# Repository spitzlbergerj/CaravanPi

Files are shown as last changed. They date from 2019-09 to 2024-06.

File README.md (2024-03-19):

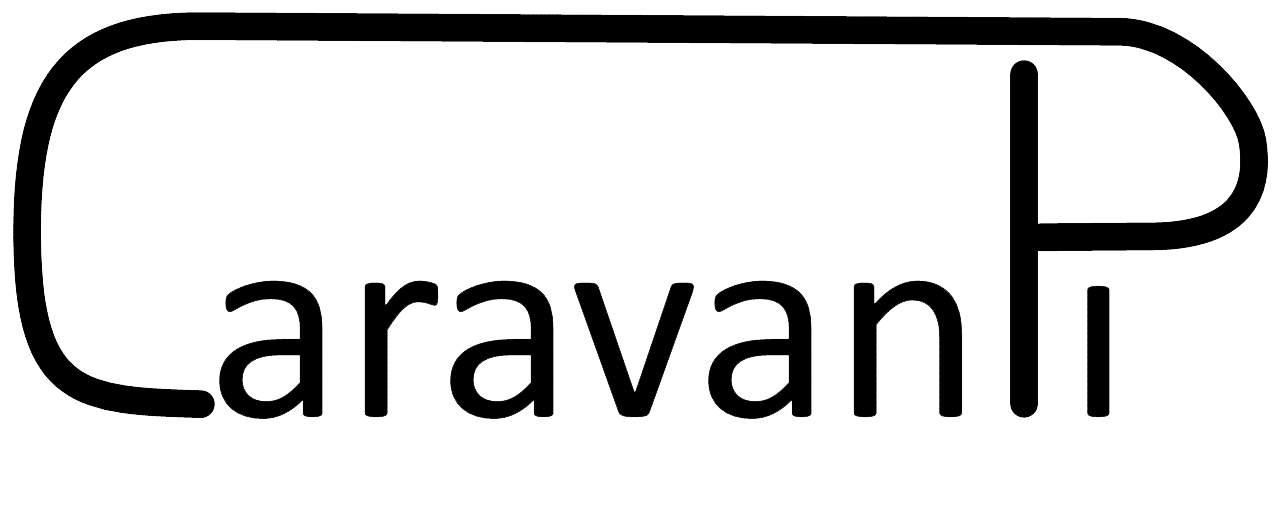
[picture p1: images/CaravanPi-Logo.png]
CaraavanPiLogo
  
# CaravanPi

ACHTUNG: Dokumentation nicht aktuell v2.0 noch nicht eingearbeitet

- [Website](https://www.CaravanPi.de)
- [Wiki](https://github.com/spitzlbergerj/CaravanPi/wiki/)
- [Platine bestellen](https://www.caravanpi.de/platine)

- [Newsletter abonnieren (Sendinblue/Brevo Plattform)](https://40fb016c.sibforms.com/serve/MUIFAH4-cq2k2-T8acJ-A43b4eFEC9NdXuY4Qsx0Z8AVap96J-xUTzrsRBFXvzXRIEBnFebbvgbXibn9NFGg8v5Qx55c4hzOQlpmxT23eU7bOGsW2ycUFhNx8PIrJcuGt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)

- [Movitation](#motivation)

## Aktualisierungen / Change Log

Details siehe / Please view [CHANGELOG.md](https://github.com/spitzlbergerj/CaravanPi/blob/master/CHANGELOG.md)

## Motivation

System zur Messung und Anzeige verschiedener Sensorenwerte in Wohnwagen, Caravans und Wohnmobilen, wie z.B. Klimawerte, Füllstände von Tanks und Gasflaschen sowie Nivellierungsdaten. Zur Darstellung wird die Software <a href="https://magicmirror.builders/">Magic Mirror</a> verwendet. 
Es existiert eine Schritt für Schritt Anleitung in deutsch. Englische Schnipsel sind bereits vorhanden und werden ausgebaut werden.
[direkt zur Anleitung](https://github.com/spitzlbergerj/CaravanPi/wiki/Home/)

Schemazeichnung | MagicMirror Anzeige (vor Grafana)
----- | -----
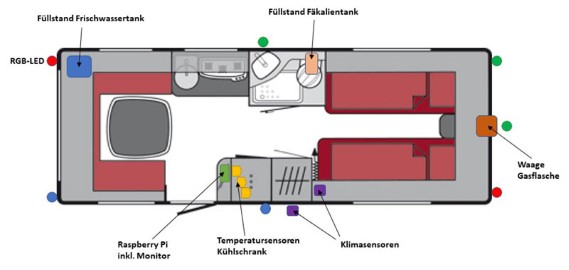
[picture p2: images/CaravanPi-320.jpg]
Schema
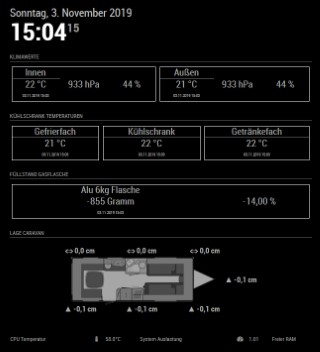
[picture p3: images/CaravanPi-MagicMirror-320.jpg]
MagicMirror
 | 
[größeres Bild](https://github.com/spitzlbergerj/CaravanPi/raw/master/images/CaravanPi.jpg) | [größeres Bild](https://github.com/spitzlbergerj/CaravanPi/raw/master/images/CaravanPi-MagicMirror.jpg) 

## Platinen Design

Die Platine liegt inzwischen in der version V6 vor in die wiederum eine Reihe von Verbesserungen eingeflossen sind.  
Vorderseite | Rückseite
----- | -----
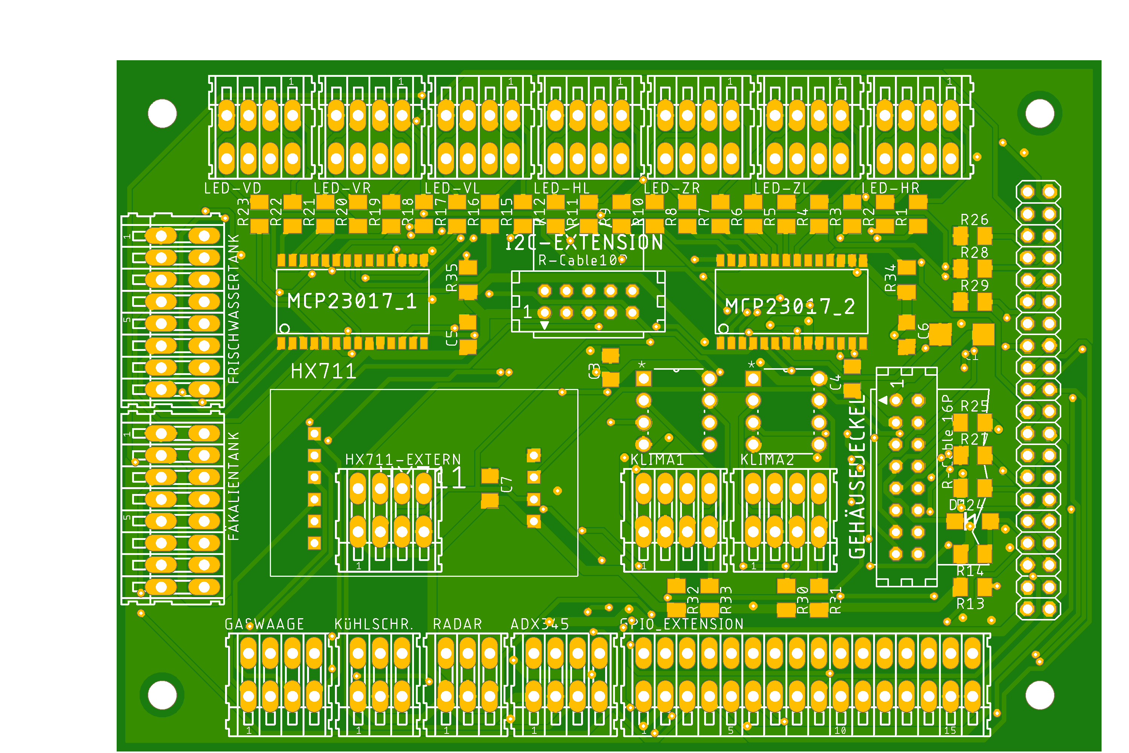
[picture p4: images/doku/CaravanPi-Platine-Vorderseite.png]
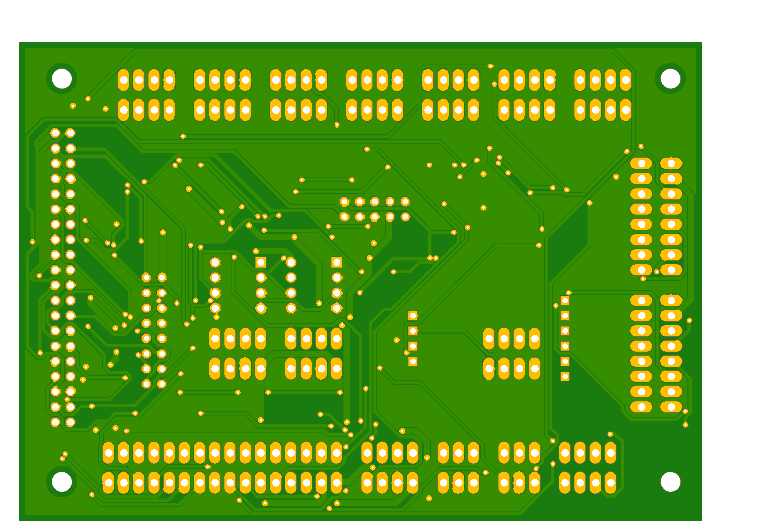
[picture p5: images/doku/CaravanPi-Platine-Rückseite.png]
 |  
Alle zum Bestellen der Platine benötigten Angaben und Dateien befinden sich im Verzeichnis circuit-board
Die Platine ist aus SMD Bauteilen aufgebaut. Als Klemmen verwendete ich früher WAGO Klemmen. Aufgrund des hohen Preises derselben bin ich inzwischen auf JST XA Stecker umgestiegen, die auch sehr viel flexibler beim Umbau sind. Bitte auf hochwertige Stecker achten, am besten original JST bauteile verwenden.
Ich kläre gerade mit JLCPCB, bei denen ich meine Platinen bestelle, ob diese Klemmen ebenfalls ab Werk aufgelötet werden können.

Ich habe beinahe immer einige Platinen vorrätig. Bitte nutzen Sie den Bestelllink oben, falls Sie Interesse an einer Platine haben.

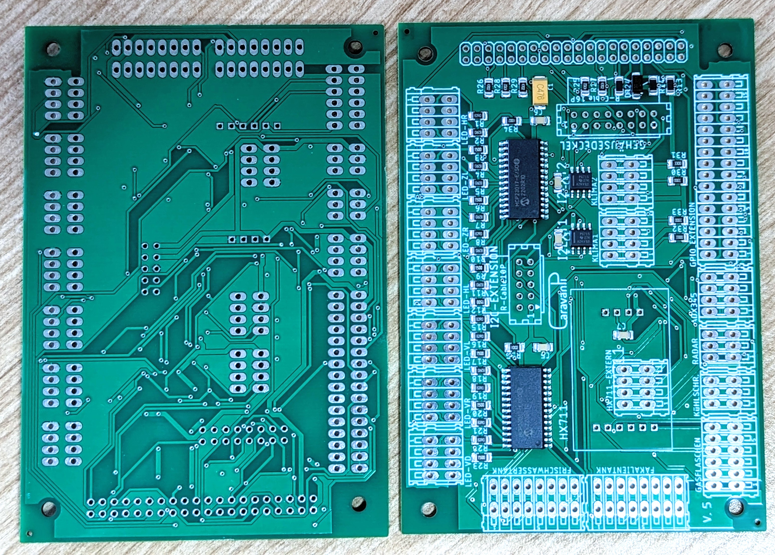
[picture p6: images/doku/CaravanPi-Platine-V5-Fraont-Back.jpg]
V5 back - front
 

## Dokumentation

Die Dokumentation findet im [Wiki](https://github.com/spitzlbergerj/CaravanPi/wiki/) statt. Dieses wird gerade neu aufgebaut, um auch alle neuen Funktionälitäten darstellen zu können.

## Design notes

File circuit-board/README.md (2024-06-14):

# Platinen Fertigung
In diesem Directory finden Sie alle Dateien, um eine Platine bei einem Dienstleister bestellen und fertigen lassen zu können.

# Versionen
Die CaravanPi Platine existiert inzwischen in mehreren Versionen

Version | Beschreibung
-----------|----
Version 1 | allererste Versuche, nicht für eine Auftragsproduktion geeignet
Version 2 | erste Version, die ich bei einem Dienstleister habe produzieren lassen <br/> enthält jedoch einen Fehler. Die Verdrahtung des VCC des Radar-Sensors war fälschlicherweise 3,3 V anstatt 5V
Version 3 | korrigierte Version, die ich erstmals bei JLCPCB inkl. SMD Bestückung habe fertigen lassen
Version 4 | Umstellung aller IC auf SMD
Version 5 | nur SMD Bauteile, Fehlerkorrektur R24 1-wire, Gaswaagen-Klemme 6 polig für A und B Kanal des HX711
Version 6 | Fehlerkorrektur HX711 mit 5V versorgt anstatt 3V3 um mehr Stabilität zu erzeugen

# Fertigung bei JLCPCB

Bei JLCPCB.com können Platinen sehr günstig, in hoher Qualität und inkl. SMD Bestückung online bestellt werden (siehe [Artikel in der Zeitschrift Make](https://www.heise.de/news/Ausprobiert-Platinen-mit-kostenloser-SMD-Bestueckung-5070776.html)). Den Bestellprozess habe ich [ausführlich beschrieben](jlcpcb.com/README.md). Alle benötigten Dateien sind in den jeweiligen Unterverzeichnissen der Versionen enthalten.

Achtung, manchmal sind nicht alle Bauteile bei JLCPCB in ausreichender Zahl vorrätig ([parts library](https://jlcpcb.com/parts)). Dies betrifft insbesondere die ICs [MCP23017](https://jlcpcb.com/parts/componentSearch?isSearch=true&searchTxt=MCP23017) und [P82B715P](https://jlcpcb.com/parts/componentSearch?isSearch=true&searchTxt=MCP23017). Diese beiden Bauteile müssen bei einer 5-Platinen-Bestellung jeweils mindestens in der Menge (stock) 10 vorrätig sein. Wer auch selbst SMD löten beherrscht, kann dennoch bestellen. Ansonsten lohnt meist das warten von einer Woche. Dann sind die Teile meist wieder vorrätig.

Der Versand aus China dauert etwa 10 - 15 Tage.

Bei der Einfuhr nach Deutschland werden Zollgebührenn fällig. Für 5 Platinen inkl. SMD Bestückung der Version 3 ohne MCP23017 habe ich im Juni 2021 22 EUR Zoll bezahlt.

# Abmessungen

Platine Abmessungen
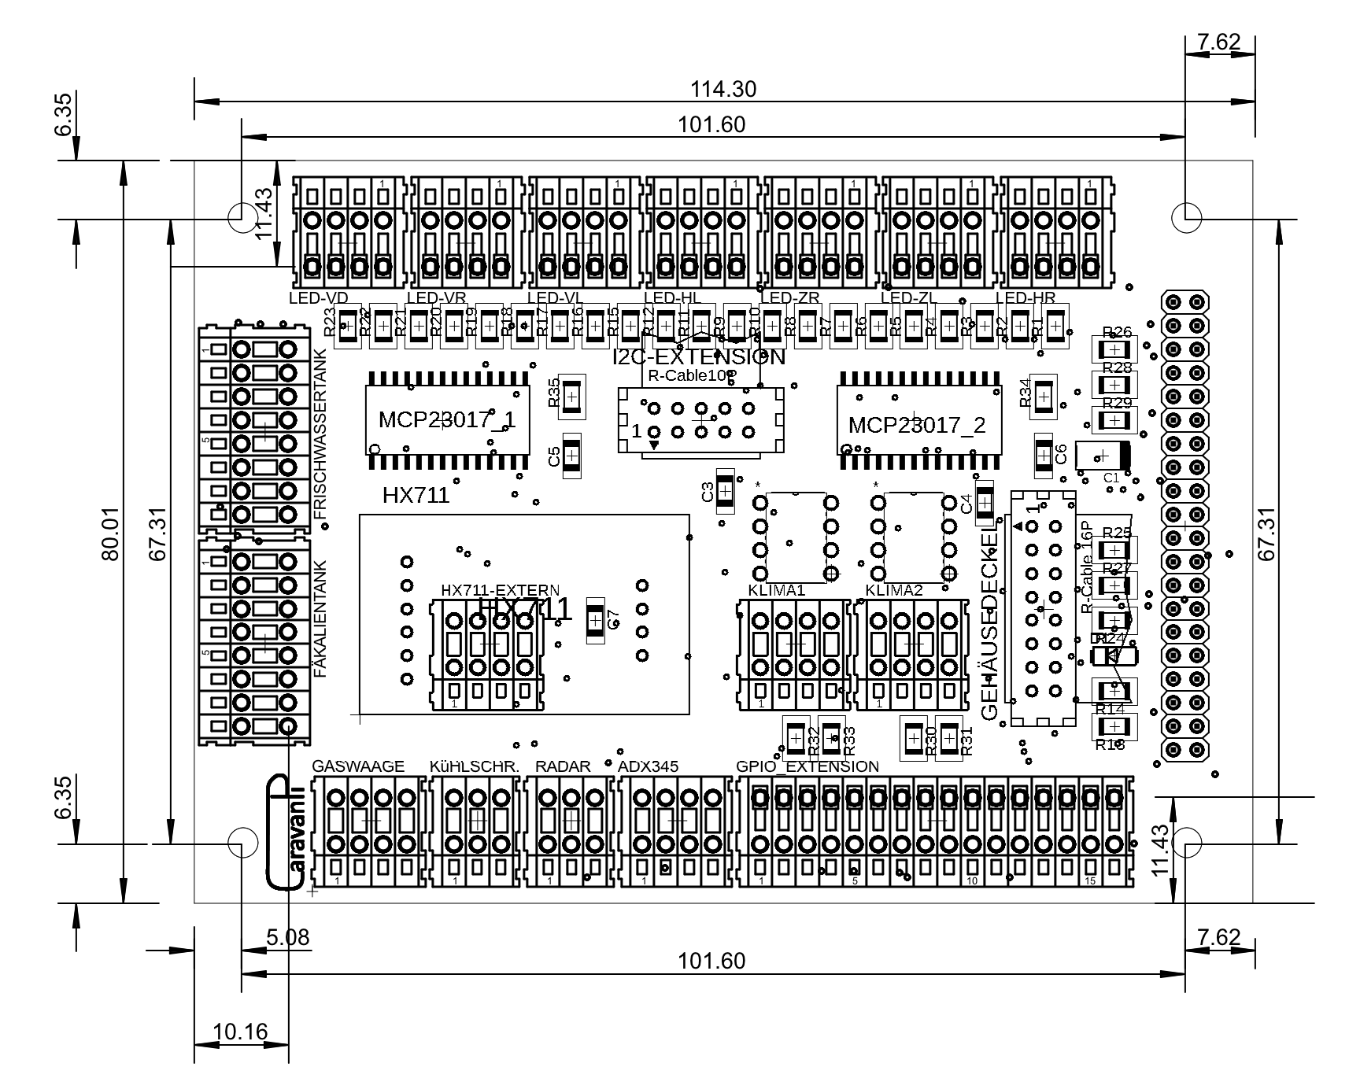
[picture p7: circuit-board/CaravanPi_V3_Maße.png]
CaravanPiPlatine
  

# 3D Druck Bauteile für die CaravanPi Platine

Ich habe zwei Halterungen zur Montage der Platine in einem größeren Gehäuse konsturiert, so dass die Platine quasi mit doppelseitigem Klebeband montiert werden kann. Eine Halterung enthält Möglichkeiten zur Kabelführung

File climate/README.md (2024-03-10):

# CaravanPi
System zur Messung und Anzeige verschiedener Werte in Wohnwagen und Reisemobilen, u.a. Klimawerte, Füllstände und Niveaudaten. Magic Mirror wird für die Präsentation verwendet.

# Python Skripte

## climate2file.py
python3 /home/pi/CaravanPi/climate/climate2file.py [-h] [-i {76,77}] [-f] [-s] [-c]

Lesen des Klimasensors und Verarbeiten der Sensorwerte

optional arguments:
    -h, --help                  show this help message and exit
    -i {76,77}, --i2c {76,77}   I2C Bus Adresse (76 (default) oder 77)
    -f, --file                  schreiben in ein File - obsoloet durch globale xml Konfiguration
    -s, --screen                ausgeben am Bildschirm
    -c, --check                 führt nur einen Funktionscheck des Sensors aus

# Climate sensors

Ich verwende den Bosch BME280 zur Bestimmung der Temperatur, des Luftdrucks und der Luftfeuchtigkeit. Der Sensor ermittelt diese Daten zuverlässig auf kleinstem Raum. Ich verwende zwei dieser Sensoren. Einer überwacht den Innenraum des Wohnwagens, einer den Außenbereich. Dort habe ich ihn auf dem Dach, allerdings beschattet durch eine Antennenplattform, angebracht.

## I2C Bus Extender
Der von mir verwendete BME280 kann über den I2C-Bus angesprochen werden. Da ich die beiden Sensoren optimal im und am Wohnwagen platzieren möchte (z.B. weit weg von Wärmequellen wie Raspberry oder Kühlschrank), sind I2C Bus Extender notwendig. Als Kabel verwende ich ein Cat6 Kabel.

# BME280 bzw. BME680
Im Verzeichnis beispielskripte finden sich Skripte, die statt dem BME280 den BME680 verwenden, der neben den Werten des BME280 auch noch einen Luftqualitätswert ausgibt.

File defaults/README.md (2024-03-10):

# CaravanPi
System zur Messung und Anzeige verschiedener Werte in Wohnwagen und Reisemobilen, u.a. Klimawerte, Füllstände und Niveaudaten. Magic Mirror wird für die Präsentation verwendet.

# Konfigurationswerte

Eine ganze Reihe von Sensoren muss vor dem Einsatz justiert werden. Es ist zum Beispiel fast unmöglich, den 3-Achsen-Positionssensor im Bezug zum Caravan absolut waagerecht zu montieren. Die Kompensationswerte werden in einer xml Datei in diesem Verzeichnis gespeichert. Außerdem werden in dieser xml Werte wie das Leergewicht der Gasflasche gespeichert, die Abmessungen des Wohnwagens und eine ganze Reihe von Konfigurationswerten für den CaravanPi an sich.

## allgemeine Konfiguration - caravanpiDefaults

countGasScales
  Anzahl Gasflaschenwaagen

countTanks
  Anzahl Tanks

write2file
  sind die Wertze Dateien im Verzeichnis values zu schreiben? 0 = nein, 1 = ja

write2MariaDB
  sollen die Werte in die Datenbank geschriebenwerden? 0 = nein, 1 = ja

send2MQTT
  sollen die Werte per MQTT versandt werden? 0 = nein, 1 = ja

MariaDBhost
MariaDBuser
MariaDBpasswd
MariaDBdatabase
  Anmeldeinformationen für die Datenbank

MQTTbroker
MQTTport
MQTTuser
MQTTpassword
  Anmeldeinformationenfür den MQTT Broker

## Abmessungen des Wohnwagens oder Wohnmobils 

- length over all
  - length of the caravan over all 
- width
  - width of the caravan over all
- lenght body
  - legth of the body of the caravan without drawbar
  
## Gaswaage und Gasflasche (gasScaleDefaults1)

- tare
  - value from gas scale without a gas cylinder 
- empty weight
  - weight of the empty gas cylinder
- full weight
  - weight of the full gas cylinder

## Bedeutung einger Konfigurationswerte

- adjustX
  - X-Wert, wenn der Wohnwagen in horizontaler Position steht
- adjustY
  - Y-Wert, wenn der Wohnwagen in horizontaler Position steht
- adjustZ
  - Z-Wert, wenn der Wohnwagen in horizontaler Position steht
- toleranceX
  - Abweichung in X-Richtung, die noch als horizontal angesehen wird 
- toleranceY
  - Abweichung in Y-Richtung, die noch als horizontal gilt
- approximationX
  - bei welcher Abweichung von der Horizontalen sollen die LEDs blinken
- approximation Y
  - bei welcher Abweichung von der Horizontalen die LEDs blinken sollen
- distRight
  - Abstand des Sensors von der rechten Seite
- distFront
  - Abstand des Sensors von der Frontseite
- distAxis
  - Abstand des Sensors von der Achse in Längsrichtung

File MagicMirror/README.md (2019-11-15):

# Display CaravanPi values through Magic Mirror
CaravanPi uses the MagicMirror software to display all measurement results. For MagicMirror, corresponding CaravanPi modules have been developed, which are described in more detail below. 

The subdirectories config and css contain corresponding sample files which can be used to configure the MagicMirror. For this purpose, the corresponding passages from the individual files must be entered into the corresponding files in the Magic Mirror directory. 

## Magic Mirror modules
The following modules were created:

- [MMM-CaravanPiClimate](https://github.com/spitzlbergerj/MMM-CaravanPiTemperature)
- [MMM-CaravanPiGasWeight](https://github.com/spitzlbergerj/MMM-CaravanPiGasWeight)
- [MMM-CaravanPiPosition](https://github.com/spitzlbergerj/MMM-CaravanPiPosition)
- [MMM-CaravanPiTemperature](https://github.com/spitzlbergerj/MMM-CaravanPiTemperature)

### MMM-CaravanPiClimate
The MMM-CaravanPiClimate module displays climate values from the BME280 sensors. The corresponding Python scripts in CaravanPi can be found in the CaravanPi/climate/ directory.



### MMM-CaravanPiGasWeight
The MMM-CaravanPiGasWeight module displays measured values from the gas cylinder scale. The corresponding Python scripts in CaravanPi can be found in the CaravanPi/gas-weight/ directory.



### MMM-CaravanPiPosition
The MMM-CaravanPiPosition module displays measured values and calculation results based on them from the ADXL345 position sensor. The corresponding Python scripts in CaravanPi are located in the CaravanPi/position/ directory.



### MMM-CaravanPiTemperature
The MMM-CaravanPiTemperature module displays measured values from the DS18B20 wired thermal sensors. The corresponding Python scripts in CaravanPi can be found in the CaravanPi/temperature/ directory.



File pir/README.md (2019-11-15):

# CaravanPi
System for measuring and displaying various values in caravans and motor homes, including climate values, filling levels and levelling data. Magic Mirror is used for presentation.

## PIR Sensor

These scripts are used to control the PIR sensor. This in turn controls the screen, which only displays values as long as motion is detected.

**In the meantime I tested the modules available at MagicMirror to control the PIR sensor and now use one of these modules instead of the script here.**

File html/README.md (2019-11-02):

# CaravanPi

## configuration websites

This multi-page website is used to configure the default values for the gas scale and the position sensor.

These web pages can also be used to calibrate the position sensor and the gas scale.

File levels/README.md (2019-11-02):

# CaravanPi
System for measuring and displaying various values in caravans and motor homes, including climate values, filling levels and levelling data. Magic Mirror is used for presentation.

## Levels of water and waste-holding tanks

under construction

With the help of the scripts still to be developed here, the levels of the water tank and the waste-holding tank are to be read out.

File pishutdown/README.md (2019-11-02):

# CaravanPi
System for measuring and displaying various values in caravans and motor homes, including climate values, filling levels and levelling data. Magic Mirror is used for presentation.

## Shutdown Pi through a tactile switch

To switch off the Raspberry Pi I use a tactile swith and the script published at heise.de. By the skillful choice of the GPIO pin 5 the button can switch the Pi on again.

(https://www.heise.de/ct/hotline/Ein-Ausschalter-fuer-Raspberry-Pi-und-Raspi-Zero-3892620.html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)

Since GPIO pin 5 is also needed for the I2C bus, an additional transistor is necessary.

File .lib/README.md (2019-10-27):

# CaravanPi
System for measuring and displaying various values in caravans and motor homes, including climate values, filling levels and levelling data. Magic Mirror is used for presentation.

## .lib

libraries for the used sensors

hx711py from https://github.com/tatobari/hx711py
I have adapted this library so that it is now python3 compatible. For this I used 2to3.

mcp23017.py von http://www.gsurf.de/mcp23017-i2c-mit-python-steuern/

ledClass.py zur Ansteuerung der LEDs über Threads

filesCaravan.py contains functions for reading and writing default files

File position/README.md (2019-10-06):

# CaravanPi
System for measuring and displaying various values in caravans and motor homes, including climate values, filling levels and levelling data. Magic Mirror is used for presentation.

## position calculation (Technical details see below)

Normally you align a caravan by measuring the position with a spirit level. The spirit level is placed once in the longitudinal direction and once in the transverse direction, e.g. on the floor of the caravan. The accuracy of this usual method depends on the accuracy of the spirit level and the quality of the floor. Everyone knows the situation where a caravan that has been levelled over the floor no longer appears horizontal when the spirit level is placed on the table or kitchen unit.

Therefore the measuring method of the CaravanPi was provided with several adjustable tolerance values. You must determine yourself which tolerance values are the correct ones for your caravan. I give here some recommendations.

A very good to good (= expensive) spirit level normally measures with an accuracy of approx. 1mm / meter. Together with the reading accuracy that can be achieved in the situation of a holiday starting hopefully immediately and the fact that the caravan floor is generally not level, a deviation of approx. 2 - 3 cm between the corners of the caravan and the horizontal appears to be sufficiently accurate.

## Technical details

The ADXL345 3-axis acceleration sensor used is capable of detecting even vibrations of a refrigerator as a change in position. According to technical specification it has an accuracy of approx. 0.0039 g (acceleration due to gravity). This corresponds to a measurable angle of approx. 0.23 degrees. With a caravan of 7 meters long and 2.3 meters wide and a positioning of the sensor at 2/3 of the length and 2/3 of the width respectively, the result is a measurable deviation from the length of approx. 18 mm and in the width of approx. 6 mm. 
 
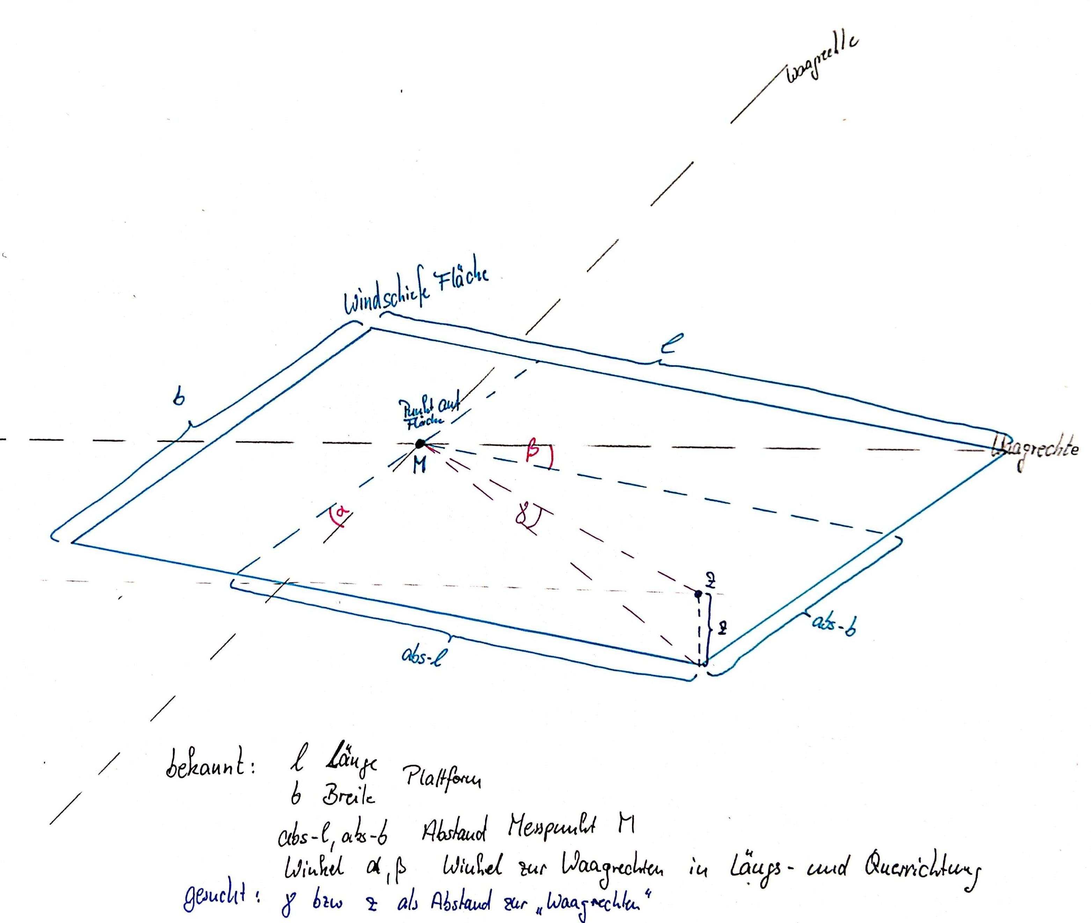
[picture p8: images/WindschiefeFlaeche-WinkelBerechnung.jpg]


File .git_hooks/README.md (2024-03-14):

ACHTUNG:
Damit die git hooks funktionieren müssen die beiden Dateien hier ins Verzeichnis .git/hooks kopiert werden.

Außerdem muss ein Verzeichnis .git_sensible_backup angelegt werden

Hier die Kommandos

cd ~/CaravanPi
cp .git_hooks/*commit .git/hooks
chmod +x .git/hooks/*commit
mkdir ~/CaravanPi/.git_sensible_backup

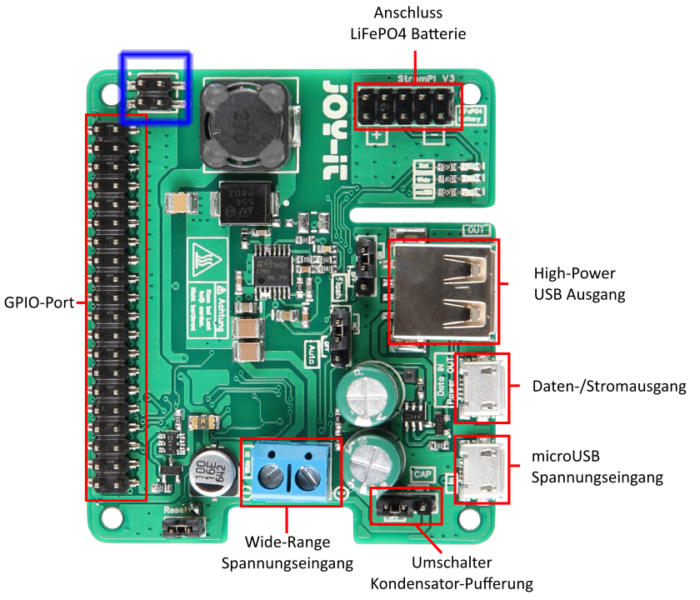
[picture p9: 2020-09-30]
images/doku/strompi3-pinout-700x600-PoE.png

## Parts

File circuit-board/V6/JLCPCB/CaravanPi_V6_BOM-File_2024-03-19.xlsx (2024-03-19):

Comment | Designator | footprint | LCSC Part
1206W4F4702T5E | R25,R26,R27,R28,R29 | M1206 | C25833
CA45-C016K476T | C1 | SMC_C | C123258
1206W4F820JT5E GRUEN, BLAU | R1,R4,R7,R10,R15,R18,R21, R2,R5,R8,R11,R16,R19,R22 | M1206 | C17980
1206W4F1500T5E ROT | R3,R6,R9,R12,R17,R20,R23 | M1206 | C17917
CRCW12064K70FKEA | R13,R14,R24 | M1206 | C242482
1206W4F1002T5E | R34,R35 | M1206 | C17902
S1D-13-F | D1 | DO214AC | C154769
CL31B104KBCNNNC | C3,C4,C5,C6,C7 | C1206 | C24497
1206W4F3300T5E | R30,R31,R32,R33 | M1206 | C17930
MCP23017SO | MCP23017_1,MCP23017_2 | SOIC-28_300mil | C629440
P82B715PN,112SOIC8 I2C-bus extender | I2EXT1, I2EXT2 | SOP127P600X175-8N | C2649394

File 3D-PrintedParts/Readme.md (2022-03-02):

In diesen Verzeichnis finden Sie 3D-Daten für den 3D-Druck.

# Gehäuse für die Frischwassertank Schaltung

Dieses Gehäuse nimmt die Frischwassertank Schaltung auf. Das Gehäuse wurde so entwickelt, dass die Kabel einfach zugeführt werden können 

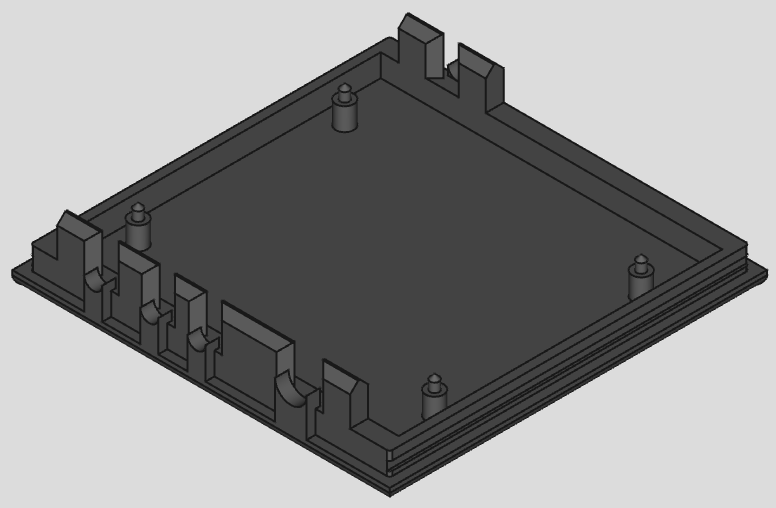
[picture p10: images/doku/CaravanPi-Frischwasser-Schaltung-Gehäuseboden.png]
CaravanPi Frischwassertank Schaltung Deckel
 

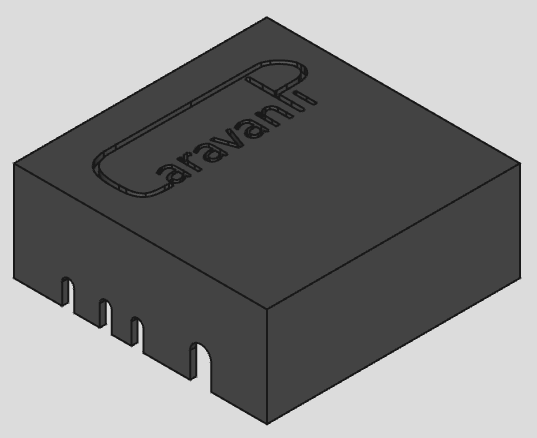
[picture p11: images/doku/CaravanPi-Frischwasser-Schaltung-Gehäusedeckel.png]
CaravanPi Frischwassertank Schaltung Boden
 

https://www.thingiverse.com/thing:4866884

# Basis Platte für die CaravanPi Hauptplatine 

Damit kann die Hauptplatine mit einem doppelseitigen Klebeband in ein Kauf-Gehäuse montiert werden, ohne dass Löcher in den Boden gebohrt werden müssen. 

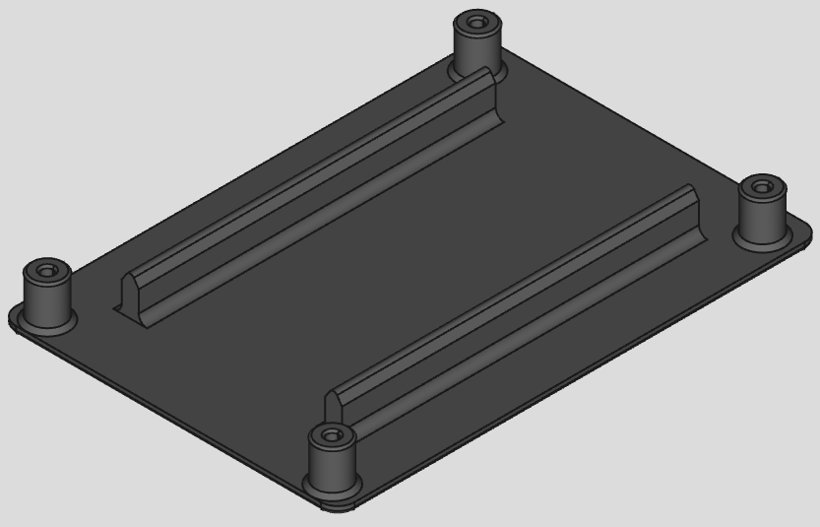
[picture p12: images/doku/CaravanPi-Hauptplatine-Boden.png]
CaravanPi Frischwassertank Schaltung Boden
 

https://www.thingiverse.com/thing:4866883

# Halterungen für Reed Kontakte zur Ermittlung des Füllstands am Fäkalientank

Diese Halterungen, die derzeit bei den Sockelvarianten nur exemplarisch hochgeleden wurden, können über Parameter an die benötigten Höhen angepasst werden. Aufgeklebt werden die Halterungen mit Tesa Strips mini

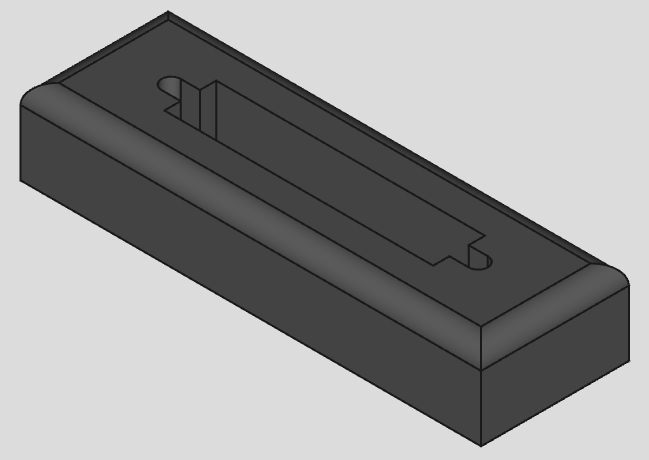
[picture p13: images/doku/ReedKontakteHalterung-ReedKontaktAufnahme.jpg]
CaravanPi Fäkalientank Reed Kontakte Halterung - Aufnahme Reed Kontakt (Oberteil)
 

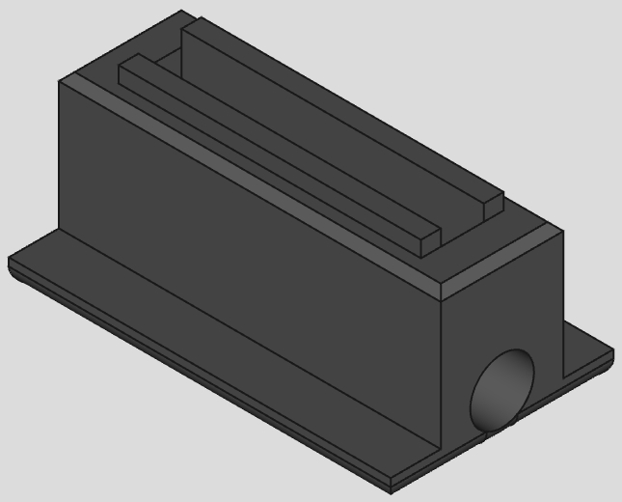
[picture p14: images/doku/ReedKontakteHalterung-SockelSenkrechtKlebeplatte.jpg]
CaravanPi Fäkalientank Reed Kontakte Halterung - Sockel senkrechte Montageplatte (Unterteil)
 

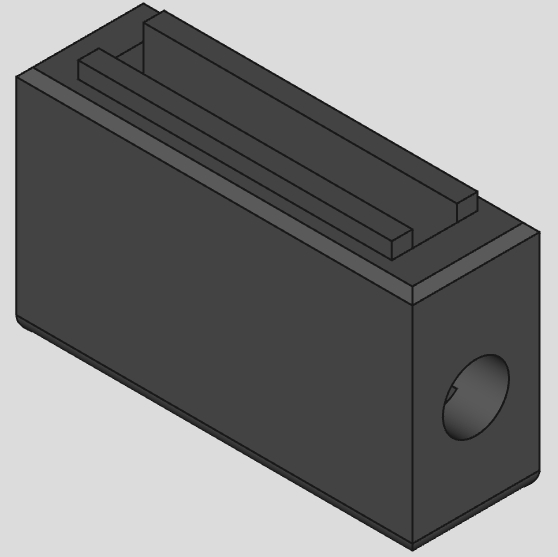
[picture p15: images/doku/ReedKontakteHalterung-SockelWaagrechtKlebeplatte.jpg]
CaravanPi Fäkalientank Reed Kontakte Halterung - Sockel waagrechte Montageplatte (Unterteil)


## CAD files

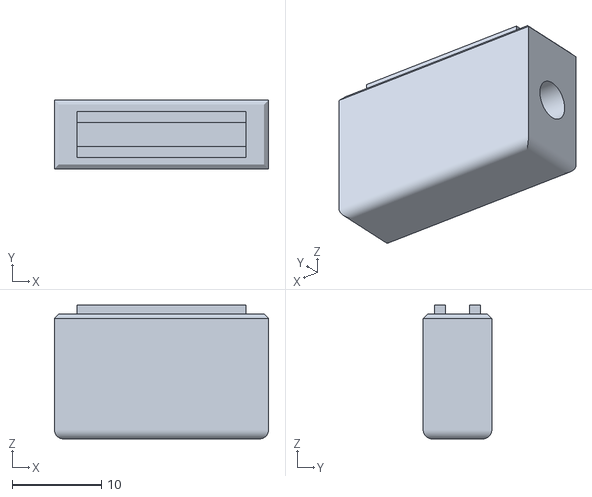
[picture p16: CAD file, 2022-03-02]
3D-PrintedParts/ReedKontakteHalterung-SockelWaagrechtKlebeplatte.stl
24.0 x 7.70 x 15.0

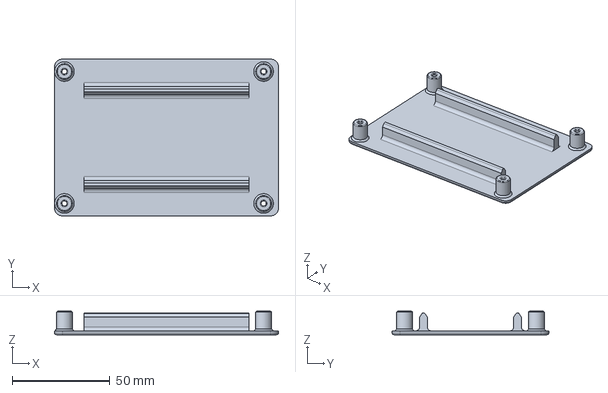
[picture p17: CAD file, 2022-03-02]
3D-PrintedParts/BasisplatteHauptplatine.FCStd
114.3 x 80.0 x 12.0 mm

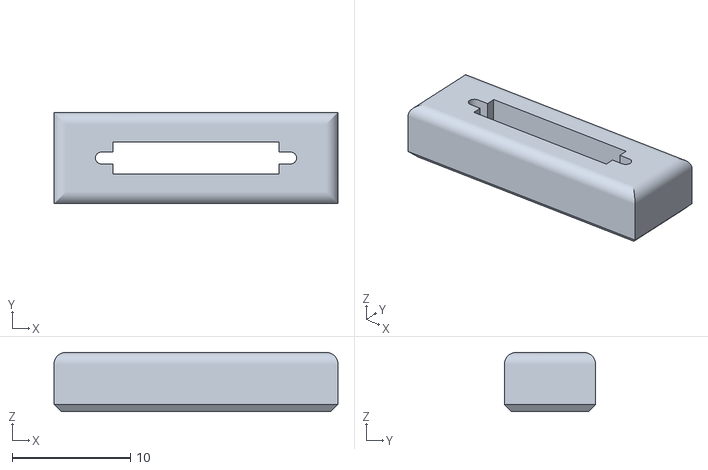
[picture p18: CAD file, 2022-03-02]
3D-PrintedParts/ReedKontakteHalterung-ReedKontaktAufnahme.stl
24.0 x 7.70 x 5.00

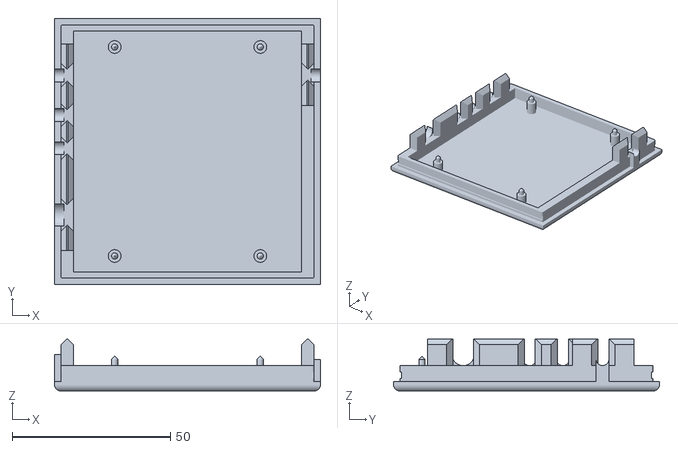
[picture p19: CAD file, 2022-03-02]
3D-PrintedParts/GehäuseFrischwassertankschaltungBoden.stl
84.0 x 84.0 x 16.4

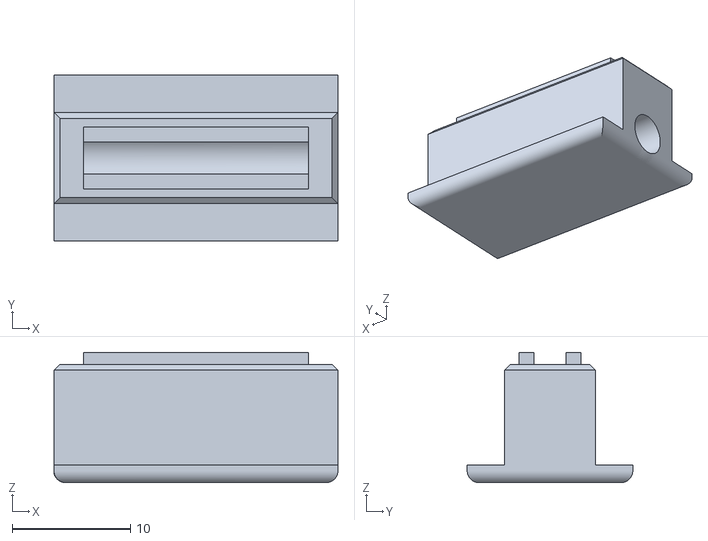
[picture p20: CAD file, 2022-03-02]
3D-PrintedParts/ReedKontakteHalterung-SockelSenkrechtKlebeplatte.stl
24.0 x 14.0 x 11.0

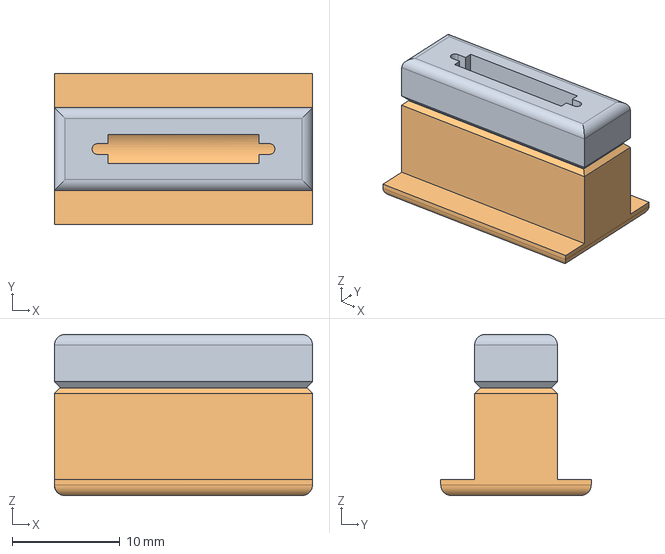
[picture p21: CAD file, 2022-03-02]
3D-PrintedParts/ReedKontakteHalterung.FCStd
24.0 x 14.0 x 15.0 mm
Reed Kontakt Aufnahme
Sockel Senkrecht Klebeplatte

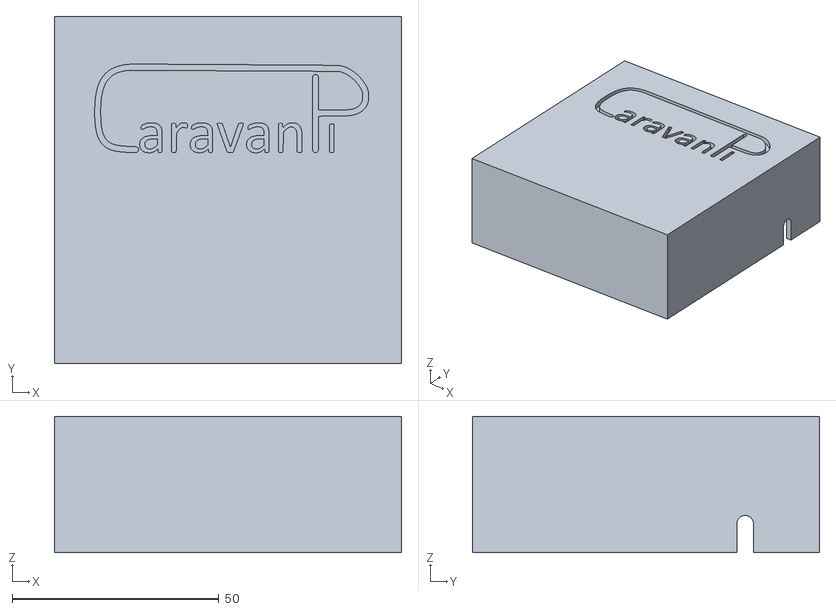
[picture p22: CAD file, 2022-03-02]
3D-PrintedParts/GehäuseFrischwassertankschaltungDeckel.stl
84.0 x 84.0 x 33.0

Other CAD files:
3D-PrintedParts/GehäuseFrischwassertankschaltungInklLogoInlay.FCStd
3D-PrintedParts/BasisplatteHauptplatine.stl

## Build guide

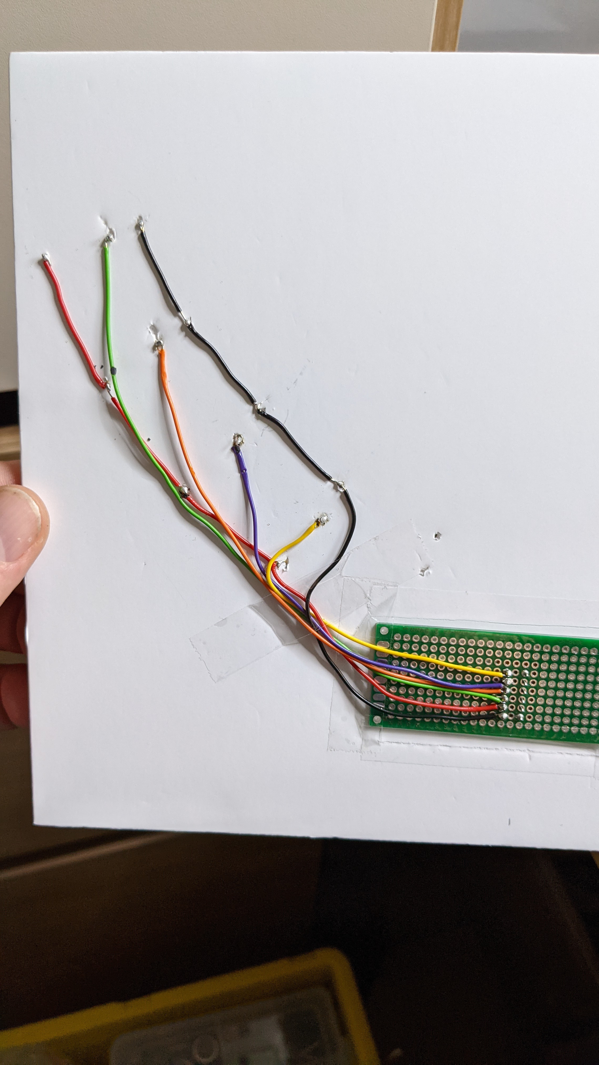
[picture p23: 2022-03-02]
images/doku/CaravanPi-Faekalientank-TestAufbauR.jpg

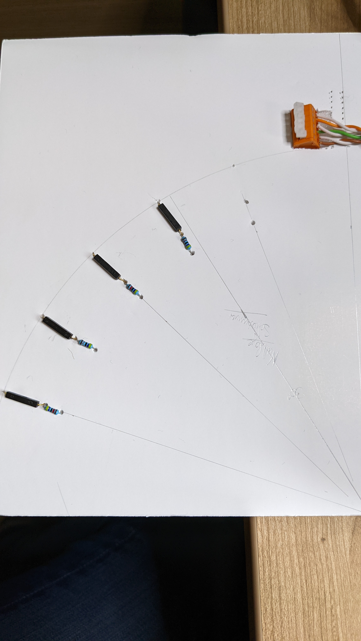
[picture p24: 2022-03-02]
images/doku/CaravanPi-Faekalientank-TestAufbau.jpg

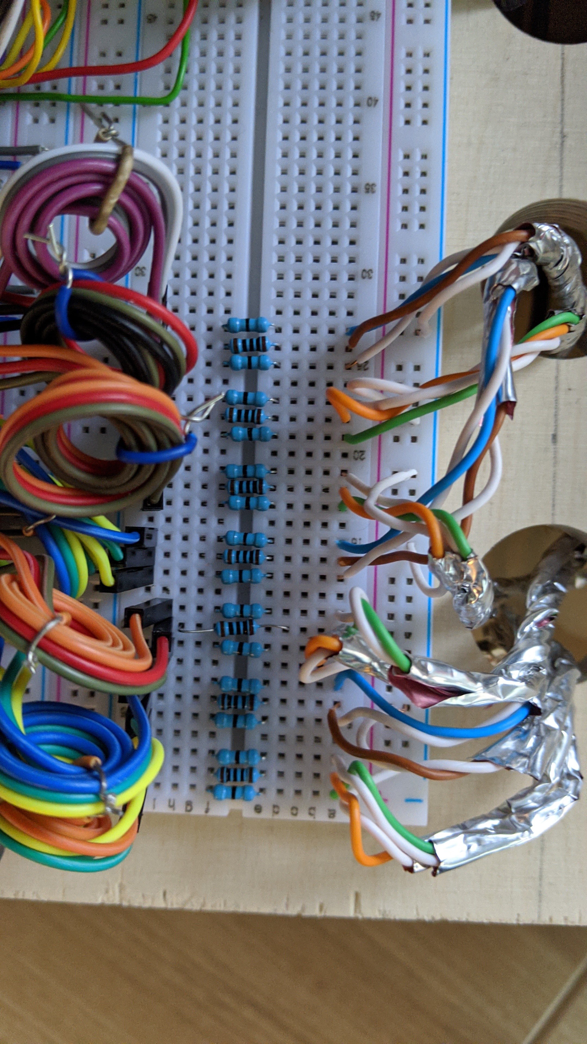
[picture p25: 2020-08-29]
images/doku/CaravanPi-LED-Testaufbau2.jpg

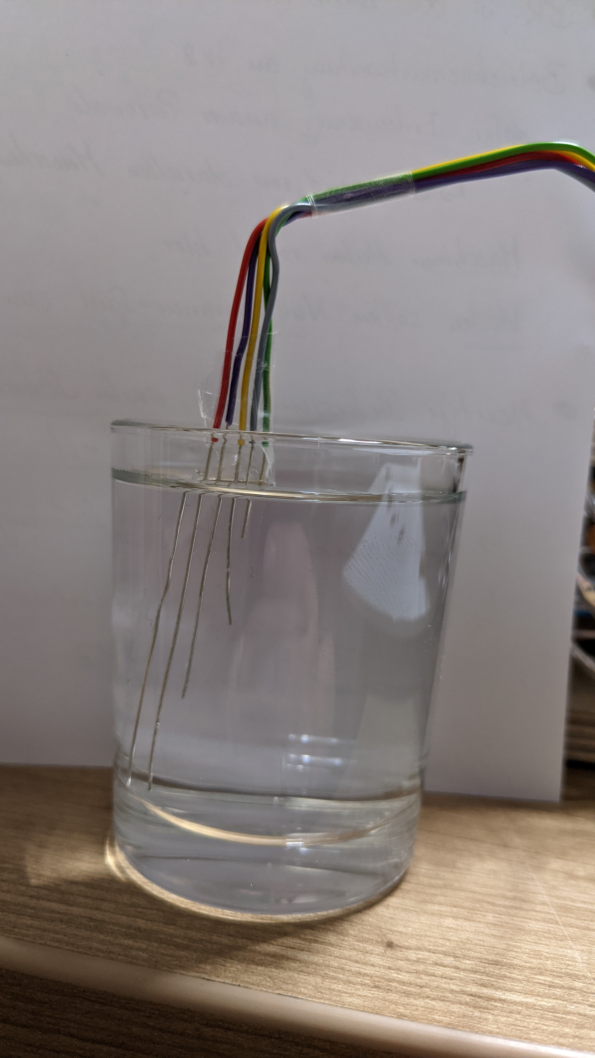
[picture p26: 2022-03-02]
images/doku/CaravanPi-Frischwassertank-Testaufbau.jpg

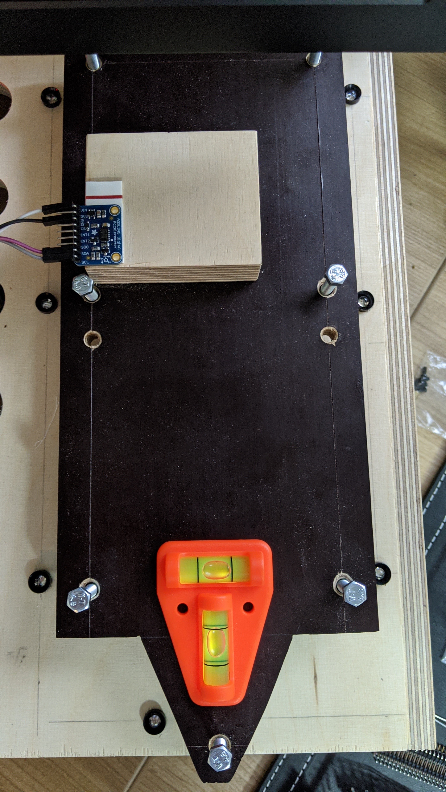
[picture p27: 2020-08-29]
images/doku/CaravanPi-LED-Testaufbau1.jpg

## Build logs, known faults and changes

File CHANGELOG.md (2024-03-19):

# CaravanPi Change Log

In dieser Datei werde ich alle relevanten Änderungen am CaravanPi dokumentieren

---

## v2.0 Einführung MariaDB, Grafana, neues Backup, Configs per xml (noch in Arbeit - development branch)

- **Konfiguration per xml Datei**
  Bisher wurden für die Konfiguration der CaravnaPi Skripte Testdateien verwendet. Diese enthielten nur die Werte, nicht aber die Felderklärungen. Das machte das Lesen der Konfigurationsdateien praktisch unmöglich. Nun wurden diese Textdateien durch eine xml Datei ersetzt, in der alle Konfigurationen enthalten sind. Die xml Datei ist besser lesbar (Optimierung noch ausstehend, dass die xml datei mit Zeilenumbrüchen geschrieben wird).
  Die Lese und Schreibskripte sind abwärtskompatibel. Werden alte Konfigurationsdateien gefunden, so werden diese in die xml Datei umgewandelt und in einem _alt Verzeichnis gesichert.

- **Backup Skript ersetzt**
  CaravanPi hatte bisher ein eigenes backup Skript. Dieses habe ich durch ein eigenes Repository ersetzt. 
  Fortan wird https://github.com/spitzlbergerj/Raspberry-Pi-Backup-Cloud genutzt.
  Noch offen: Dokumentation der Sicherung der MariaDB

- **Einführung einer Datenbank zur Speicherung der Sensorwerte**
  Die Sensorwerte können nun nicht nur in Files abgelegt werden, sondern auch in einer MariaDB. Die Zugangsdaten zur MariaDB werden in der XML abgelgt. Der Connect und die Schreibvorgänge in die Datenbank übernehmen  zentrale Funktionen in der CaravanPiFiles Class.

- **Einführung des Sendes der Sensorwerte per MQTT**
  Die Sensorwerte können nun per MQTT Messages versandt werden. Im Moment ist die Ansteuerung eines Cloud MQTT Servers vorgesehen, der für den Login User und passwort benötigt und ein Login mit TLS ohne Clientzertifikate erlaubt. Dies sind z.B. die Cloud MQTT Broker von EMQX und HiveMQ, die beide kostenfreie Accounts anbieten. Den Connect und die Sendevorgänge an den Broker übernehmen zentrale Funktionen in der CaravanPiFiles Class.

- **allgemeine Bereinigung und Härtung der vorhandenen Funktionen**
  Alle vorhandenen Skripte zur Ermittlung der Sensorwerte wurden überprüft, optimiert und insbesondere gehärtet, so dass Fehlersituationen in den Skripten abgefangen und behandelt werden, ohne die Funktionen zum Absturz zu bekommen. Das regelmäßige überprüfen der Log-Daten auf Fehlerzustände ist daher wichtiger geworden. Alle Fehlerzustände werden mit einem einleitenden ERROR kenntlicher gemacht.

- **Einführung von Grafana zur Darstellung der Sensorwerte als Verlauf**
   Neben der Datenbank MariaDB und der Datenbank-Managementsoftware phpmyadmin kommt nun Grafana zur grafischen Darstellung der Sensorwerte und deren Verlauf zum Einsatz.

- **Umstellung der CaravanPi Website auf Flask Framework**
   Die CaravanPi Website basiert nun auf dem Python Framework Flask und ist dadurch bei weitem flexibler geworden.
   Über die Website kann die Statusprüfung angestoßen werden, die Konfiguration kann eingetragen werden, Testroutinen können gestarte werden.
   Zudem sind auch Shortcuts für die Grafana Website, phpMyAdmin oder auch den magicMirror enthalten.

- **Der Status des CaravanPi kann nun über eine Statusabfrage geprüft werden**
   Alle wesentlichen Komponenten des Aufbaus werden dabei der Reihe nach geprüft und getestet. Die Konfiguration durch den Nutzer wird dabei berücksichtigt, so dass nur die Teile geprüft werden, die auch verbaut wurden.

- **Überwachung der Landstrom-Versorgung und der Bordbatterie-Versorgung**
   Als ganz neue Features wurden die Überwachung der 230V Landstromversorgung und zweier 12V Batterien (Bordbatterie und Fahrzeugbatterie) hinzugefügt.

- **Gasalarmsensor integriert**
   Zur Überwachung eventueller Propan oder Butan Konzentrationen im Caravan wurde ein MQ-2 Sensor hinzugefügt.

- **Integration der Überwachung einer Liontron Litium Batterie**
   Auch das Batteriemanagement eine LiPo batterie kann nun angesteuert und ausgelesen werden. Beispielhaft LionTron.

- **Installationsskript**
   Ein Installationsskript kann nun die Installation des CaravanPi inkl. Magicmirror, MariaDB, Grafana, myPhpAdmin und aller benötigten Libraies übernehmen.
   Dabei werden alte Konfigurationsdateien migriert. Ein Update sollte also problemfrei möglich sein, ist aber noch nicht endgültig getestet.

- **Ansteuerung von Aktoren wie ESP82 D1 mini oder Shelly integriert**
   Beispielhaft wurde ein D1 mini als Aktor integriert und die Kommunikation von und zum CaravanPi eingebaut

- **Dokumentation der Internet-Verbindung über eine Starlink-Antenne**
   noch nachzuholen.

## V 1.1 - Fehlerkorrekturen und Erweiterungen

### Hinzugefügt (Added)

- **mehrere Gasflaschen-Waagen**
  Es können nun mehrere Gasflaschen Waagen angesteuert werden. Dabei sind über die Software grundsätzlich beinahe beliebig 
  viele Waagen möglich (Beschränkung über die freien GPIO Ports). Allerdings sieht die Konfigurationswebsite derzeit nur die 
  Konfiguration von zwei Waagen vor. Über die direkte Bearbeitung der Konfigurationsdateien über einen Editor können jedoch sehr 
  einfach weitere Waagen angesteuert werden. Die CaravanPi Platinen V3 und V4 haben beim eingelöteten Breakout Board nur den 
  Channel A des HX711 an die randliegenden Klemmen geführt. Der Channel B ist jedoch leicht erreichbar und kann zusätzlich 
  verlötet werden. Die Platine V5 wird die Kontakte des Channel B auf Klemmen führen.
  - Skripte in .lib schreiben defaults mit angehängter Flaschennummer
  - defaults für Gasflaschenwaagen enthalten nun GPIO Pin Nummern zur Ansteuerung HX711 sowie die Kanalbezeichnung A oder B und die sog. Reference Unit
  - tactileSwitches.py wurde erweitert, so dass kurzer Druck Flasche 1 kalibriert, langer Druck Flasche 2
  - html Python und PHP Skripte entsprechend angepasst
  - Skritpte teilweise umbenannt

- **logrotate - Aufnahme Spannungsaufzeichnungen**
  die Datei values/voltage wird nun ebenfalls durchrotiert

### Aktualisiert (Updated)

### Korrigiert (Fixed)
- **Kalibrierung Gasflaschen-Waagen**
  Die Kallibrierung des Waagensensors HX711 war falsch programmiert. Statt einer tatsächlcihen Kalibrierung wurde lediglich das Tara 
  angepasst. Dies führte jedoch zu falschen Werten. Die Kalibrierung wurden nun vollständig neu programmiert.

## V 1.0 - Erstes Release vor der "ersten Ausfahrt"

### Hinzugefügt (Added)

- **Grundfunktionalitäten**

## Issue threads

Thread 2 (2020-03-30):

Ich habe Probleme - Dateien fehlern

IGLO70, 2020-03-30:
laut Installationsanleitung
pm2 start /home/pi/CaravanPi/pm2/ecosystem.caravanpi.js
aber
[PM2][ERROR] Script not found: /home/pi/CaravanPi/pm2/ecosystem.caravanpi.js

den Ordner pm2 gibt es gar nicht.

Ich finde das ist ein tolles Projekt, bin aber kein "Programmierer", so das ich nur die Anleitung Schritt für Schritt abarbeiten kann. Jetzt weiß ich leider nicht mehr weiter.

Als ersten Schritt möchte ich eigentlich nur die "Wasserwaage" und die Raum- Aussentemperatur aktivieren.

spitzlbergerj, 2020-03-30:
Hallo @IGLO70,

Zum ersten, das Projekt ist "work in progress" - im Moment sogar geparkt, weil ich aktuell keine Zeit zur weiterarbeiten finde.

Wo steht den der von dir angegebene installationshinweis?

Viele Grüße
Sepp

spitzlbergerj, 2020-03-30:
Noch eine frage: Hast du auf dem Raspberry den magic mirror installiert? Der liefert pm2 mit. Ohne magic mirror funktioniert der automatische Start über pm2 nicht. Dann müsstest du alles über eine crontab steuern

spitzlbergerj, 2020-03-30:
So steht das auch im Kapitel Installing pm2 and crontabs

IGLO70, 2020-03-30:
MagicMirror ist installiert und läuft auch einwandfrei. Ich kenne mich nur beim Raspberry zu wenig aus, um die *.py Scripte, zum auslesen der Sensorik richtig aufzurufen und zu starten. Die Anzeige des Wohnwagens und der Temperaturanzeigen habe ich geschaft, aber keine Werte.
Aber durch Covid19 habe auch ich mit meinem Projekt keinen Zeitdruck. Mein nächster Urlaub ist auf  xxx Zeit verschoben.

Nochmals Gratulation, ein tolles Projekt

Grüße aus der Steiermark

Ignaz

spitzlbergerj, 2020-03-30:
Hallo Ignaz,

Dann gib mir etwas Zeit. Ich habe das Projekt gerade eingemottet und muss den raspberry erst wieder auspacken. Vielleicht klappt es bis nächstes Wochenende.

spitzlbergerj, 2020-04-01:
Hallo Ignaz,
ich habe das Directory .../CaravanPi/pm2 nun auf github eingespielt. Ich konnte den Start aber nicht mehr testen.
Auf meinem Pi, von dem ich die  Dateien geholt habe, läuft pm2 und position2file.py wird vom pm2 überwacht. Ich habe aber keine weiteren Aufzeichnungen zum Einrichten des pm2 gefunden außer die im Wiki.
Magst du es einfach mal probieren bitte, ob das so schon funktioniert?
Falls pm2 sich nicht wie im Wiki starten lässt, dann muss ich noch weiter suchen.
Viele Grüße
Sepp

IGLO70, 2020-05-17:
Danke für die Dateien.

Ich habe das Projekt jetzt soweit auf einem Steckbrett aufgebaut, um den Lagesensor zu testen, und dabei habe ich so meine Probleme.

1.	Problem

Das Programm i2cdetect zeigt mir an, das der Sensor an der richtigen Adresse erkannt wird.

Im Programm werden Lagedaten aber nur manchmal, nach einem Neustart des Raspberry einmalig eingelesen. Zu 99% zeigt mir

PM2 log immer nur folgenden Meldung:

.

Da ich in Python und Java noch nie gearbeitet habe, weis ich nicht, wo ich hier weitersuchen soll.

Einen Fehler des Lagesensors kann ich ausschließen, denn an einem ESP32 angeschlossen liefert er kontinuierlich aktuelle Werte.

2.	Problem

Die Klimasensoren habe ich nicht direkt am Pi angeschlossen, sondern die Werte werden mit einem ESP32 erfasst und über Wlan und ein PHP Script in die Dateien für die aktuellen Messwerte geschrieben.

Die Dateien  haben die vorgegebene Struktur und werden auch jede Minute mit einem neuen Messwert erweitert.

Hier finde ich im MM Error log dann immer folgende Einträge:

Die aktuellen Dateien mit meinen Messwerten vom Testaufbau sind im Anhang.

Die Taster zum Einschalten, Kalibrieren usw. habe ich noch nicht angeschlossen, den dann bekomme ich den Raspberry nicht mehr in Betrieb, sondern er geht in eine Endlosschleife von Start – Ausschalten – Start – Ausschalten. Sobald nach Erscheinen des Desktop der MM Starten soll, wird er der Raspberry wieder heruntergefahren und starten danach neu.

Vielleicht können Sie die Daten einmal kurz kontrollieren und haben eine Idee woran ich momentan scheitere.

Mit besten Dank

Ignaz Lorenz

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

IGLO70, 2020-05-17:
Noch ein Nachtrag, manchmal kommt auch dieser Eintrag in den Logdateien vom MM:

Ich bin momentan hilflos, was diese Meldungen bedeuten.

Ignaz Lorenz

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

spitzlbergerj, 2020-05-17:
Hallo Ignaz,
ich kann hier die Meldungstexte nicht sehen. Daher tu ich mich schwer mit der Fehleranalyse

IGLO70, 2020-05-17:
Anscheinend wurden die Bilder im E-Mail und die Anhänge nicht mit gesendet. Ich habe das jetzt auf einen Downloadserver gepackt.

Download unter: https://we.tl/t-V489GHmWrf

Mit besten Grüßen

Ignaz Lorenz

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

spitzlbergerj, 2020-05-17:
Hallo Ignaz,

die Fehlermeldungen deuten darauf hin, dass der I2C Bus Fehler aufweist und davon nicht gelesen werden kann. Da kann ich leider nicht helfen. Bitte versuche den Bus zum Laufen zu bekommen. Dann sollten die Skripte auch funktionieren.

Viele Grüße

Josef Spitzlberger

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

IGLO70, 2020-05-17:
Ich bin gerade dabei, das gesamte System auf einem neuen Pi 4 aufzusetzen. Der nicht funktionierende i2c Bus betrifft aber nur die Lageanzeige. Die Klimadaten sind aber in den Datendateien enthalten und kommen nicht vom i2c. Trotzdem werden Sie nicht angezeigt. Hier gibt es anscheinend Probleme beim Auslesen aus der Datei. Worin hier der Fehler besteht, verstehe ich nicht.

Gibt es hierfür eine Idee.

Mit besten Grüßen

Ignaz Lorenz

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

spitzlbergerj, 2020-08-12:
Hallo Ignaz,
ich baue den CaravanPi gerade noch einmal von Grund auf neu auf und mache die DOKU dazu auch in Deutsch. Schau einfach mal ins Wiki. Vielleicht kannst du da ja auch der Reihe nach mitmachen/mitbauen
Viele Grüße
Sepp

Closed 2020-05-17.

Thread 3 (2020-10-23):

DS18D20 Single digit temperature display incorrect

spitzlbergerj, 2020-10-23:
If a temperature is to be displayed in the single-digit range, the preparation on the Magic Mirror will fail. In the corresponding file in the values directory of CaravanPi there is a second space before the temperature value which is misinterpreted by the Magic Mirror module.

spitzlbergerj, 2020-10-23:
# 1-wire output:
```
cat /sys/bus/w1/devices/28*/w1_slave
2e 01 4b 46 7f ff 0c 10 e4 : crc=e4 YES
2e 01 4b 46 7f ff 0c 10 e4 t=18875
63 00 4b 46 7f ff 0c 10 ec : crc=ec YES
63 00 4b 46 7f ff 0c 10 ec t=6187
51 01 4b 46 7f ff 0c 10 ab : crc=ab YES
51 01 4b 46 7f ff 0c 10 ab t=21062
```

# CaravanPi values

```
tail -10 /home/pi/CaravanPi/values/28-01144fea82aa

28-01144fea82aa 20201023125104 11.06
28-01144fea82aa 20201023125204  6.18

```
Zwischen ```20201023125204 ``` und ```6.18``` befinden sich zwei Leerzeichen.

spitzlbergerj, 2020-10-23:
![Uploading ScreenShot 20201023130614 .jpg…]()

spitzlbergerj, 2020-10-23:
solved with latest update

Closed 2020-10-23.

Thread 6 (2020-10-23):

Extension by a gas sensor for propane gas

spitzlbergerj, 2020-10-23:
The CaravanPi is to be extended by a sensor for propane gas. This would enable gas leaks in the caravan to be detected via the CaravanPi. An alarm could be triggered via the buzzer.

spitzlbergerj, 2024-03-16:
In Version 2 eingebaut

Closed 2024-03-16.

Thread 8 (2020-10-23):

prevent unintentional calibration

spitzlbergerj, 2020-10-23:
Currently, the calibrations for the position or the gas cylinder scale can be triggered by simply pressing a button. This way determined calibrations can be overwritten by faulty operation.

A lock should be installed to prevent unintentional calibration.

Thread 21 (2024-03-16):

BOM und CPL Datei Fehlerhaft bei V5 und V6

3DGera, 2024-03-16:
Hallo, ich bekomme bei **JLCPCB** beim einfügen der BOM und CPL Datei immer folgende Fehlermeldung

**_"File processing failed, please check your file and upload again."_**

Nun ist die Frage liegt es daran das ich die falsche Datei einfüge oder an der Hersteller Seite. Die BOM Datei ist ja als solche erkennbar, die CPL Datei leider nicht. Ich vermute mal das die CPL Datei die mit dem Namen **PnP_CaravanPi_V6_front.csv** ist.

spitzlbergerj, 2024-03-16:
Hallo Georg,
du bist mir zu schnell ;-)
Die V6 habe ich heute erst erstellt. Die BOM und CPL muss ich noch mit den richtigen Daten anlegen. Das dauert noch ein paar Tage.

Die V5 geht aber. Ich habe erst kürzlich Platinen bestellt. Ich kann Dir da auch welche zuschicken, wenn du magst.

Hier siehst du, wie ich bestellt habe. Die Dateien sollten alle im Repository sein.

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

Grüße
Sepp

3DGera, 2024-03-16:
Ich muss leider das Thema noch mal öffnen :D

Aber irgend wie sind auch die V5 Daten fehlerhaft... die Abmaße passen nicht zu deinem Bild und auch hier bekomme ich die Fehlermeldung vom 1. Beitrag

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

Könntest du noch mal schauen ob die Daten die richtigen sind?

spitzlbergerj, 2024-03-16:
Ok, Georg,
ich schaue mir das an. Das dauert aber ein paar Tage.
ich hatte gerade probiert, die Bestellung zu reordern. Das hat funktioniert bis auf das Thema, dass ein angegebenes Bauteil gerade wieder out of Stock ist und ein alternatives gefunden werden müsste.
bei mir haben die Dateien also funktioniert.
Wie gesagt, ich melde mich.
Ansonsten gerne nochmal der Hinweis, ich habe noch welche .... ;-) Aber das entscheidest natürlich du.
Grüße
Sepp

3DGera, 2024-03-16:
Leider kann man dir nicht Privat schreiben... Wie kann ich den von dir eine Platine bekommen?

spitzlbergerj, 2024-03-16:
Hallo Georg,

Bitte fülle einfach dieses Formular aus. Danke

https://www.la-gondola-barocca.de/caravanpi-platine/

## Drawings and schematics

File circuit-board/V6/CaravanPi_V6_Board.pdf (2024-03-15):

7.62

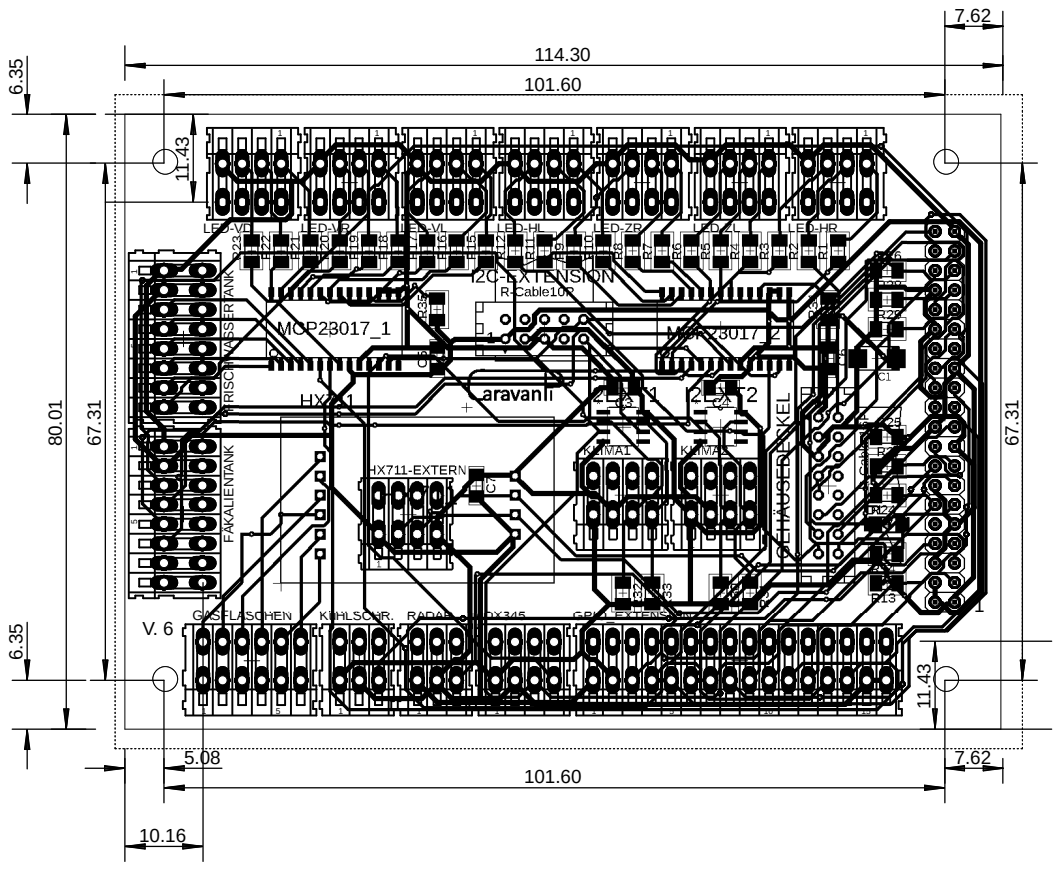
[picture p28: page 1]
ADX345; FRISCHWASSERTANK FÄKALIENTANK; KüHLSCHR.; GPIO_EXTENSION; LED-VD; LED-VR; LED-VL; LED-HL; LED-ZR; LED-ZL; LED-HR; GASFLASCHEN; RADAR

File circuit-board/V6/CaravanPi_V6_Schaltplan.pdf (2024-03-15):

A

A

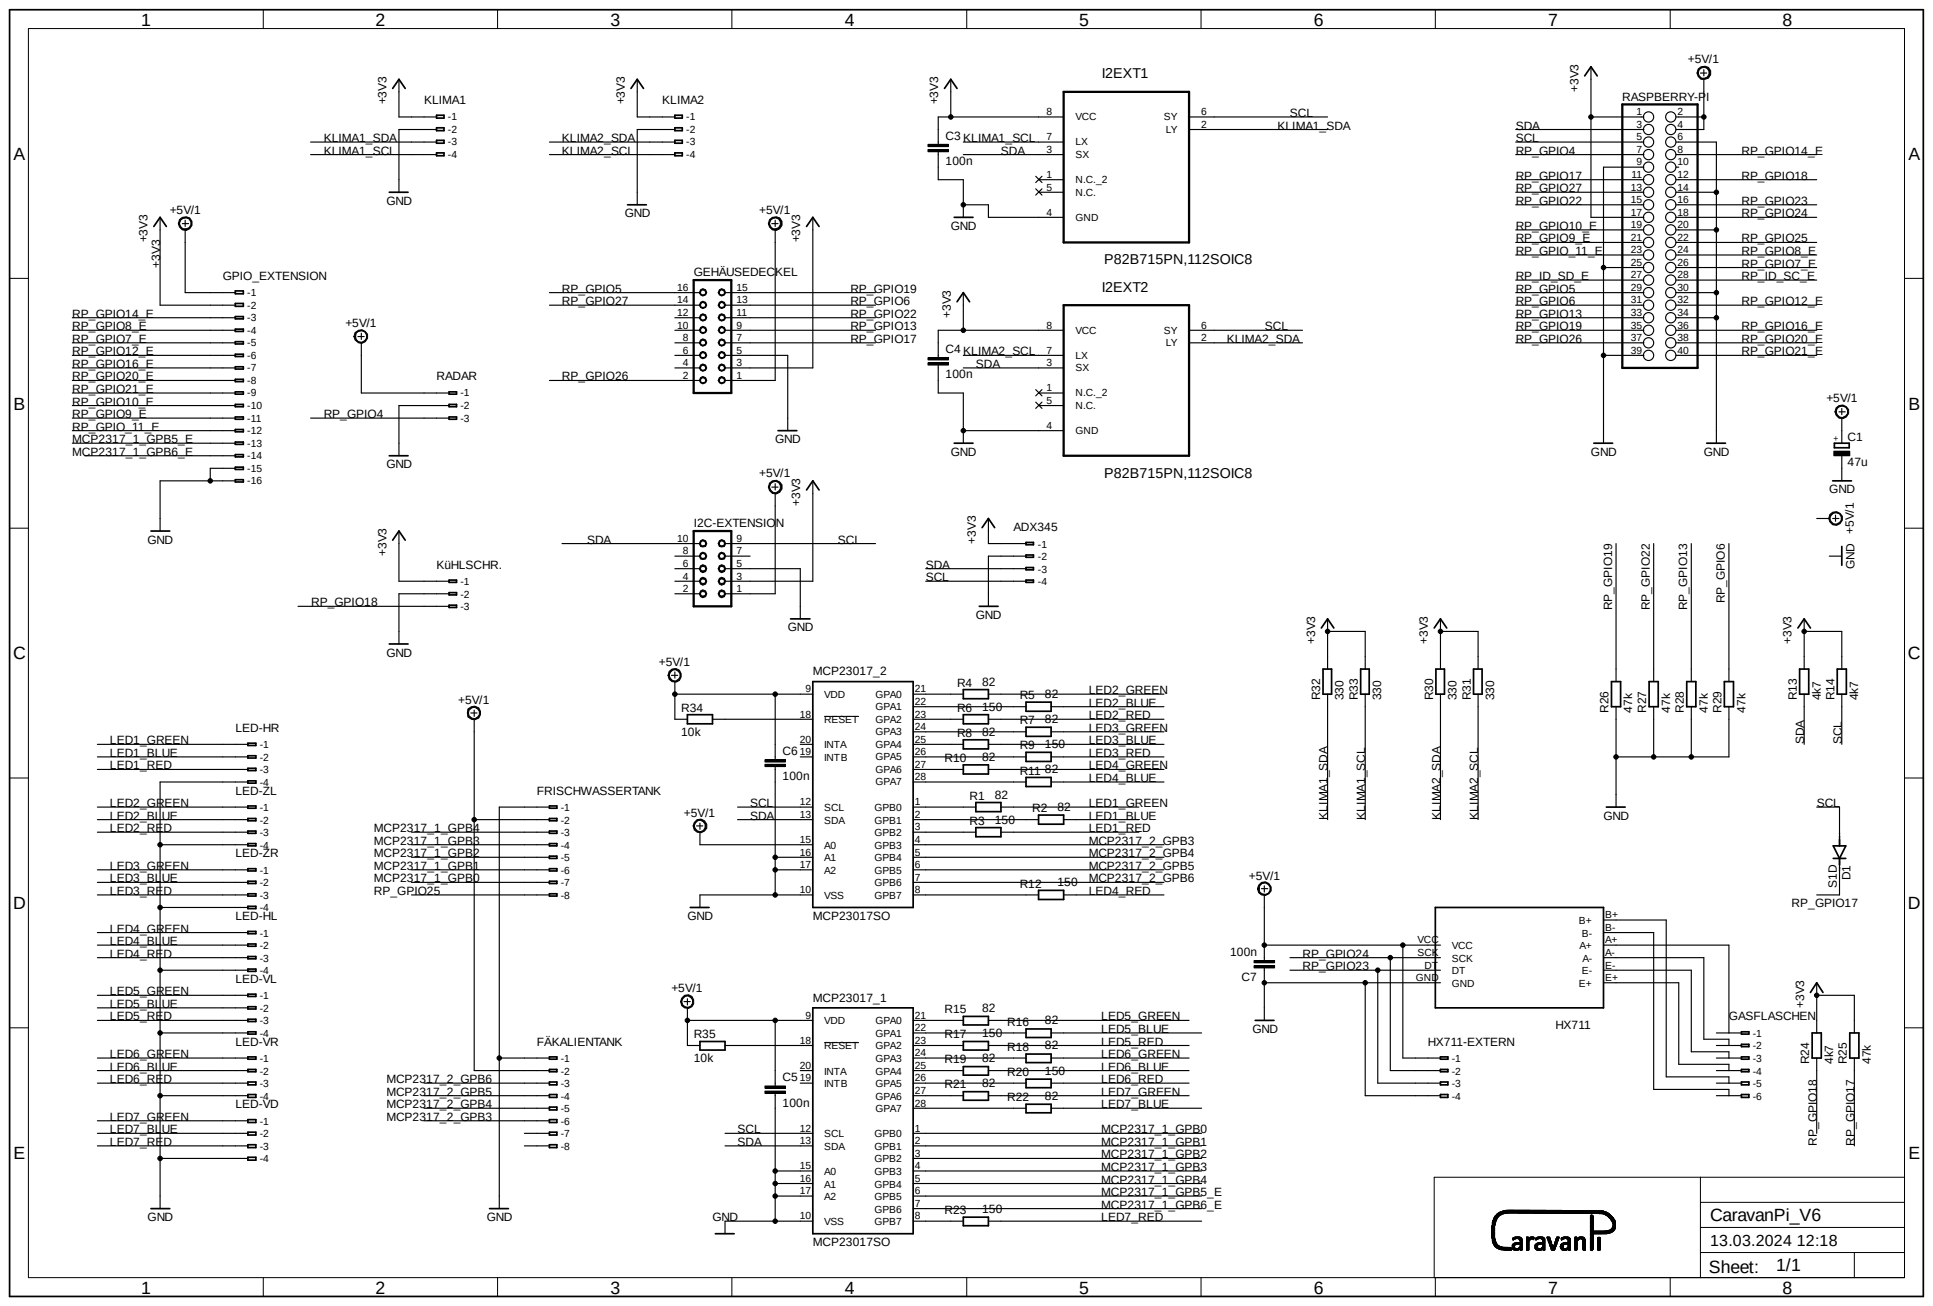
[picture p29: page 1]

KLIMA1_SCL 7 | | 2 KLIMA1_SDA

7 R23 150 MCP2317_1_GPB6_E | CaravanPi_V6

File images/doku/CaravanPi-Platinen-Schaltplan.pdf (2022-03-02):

A

A

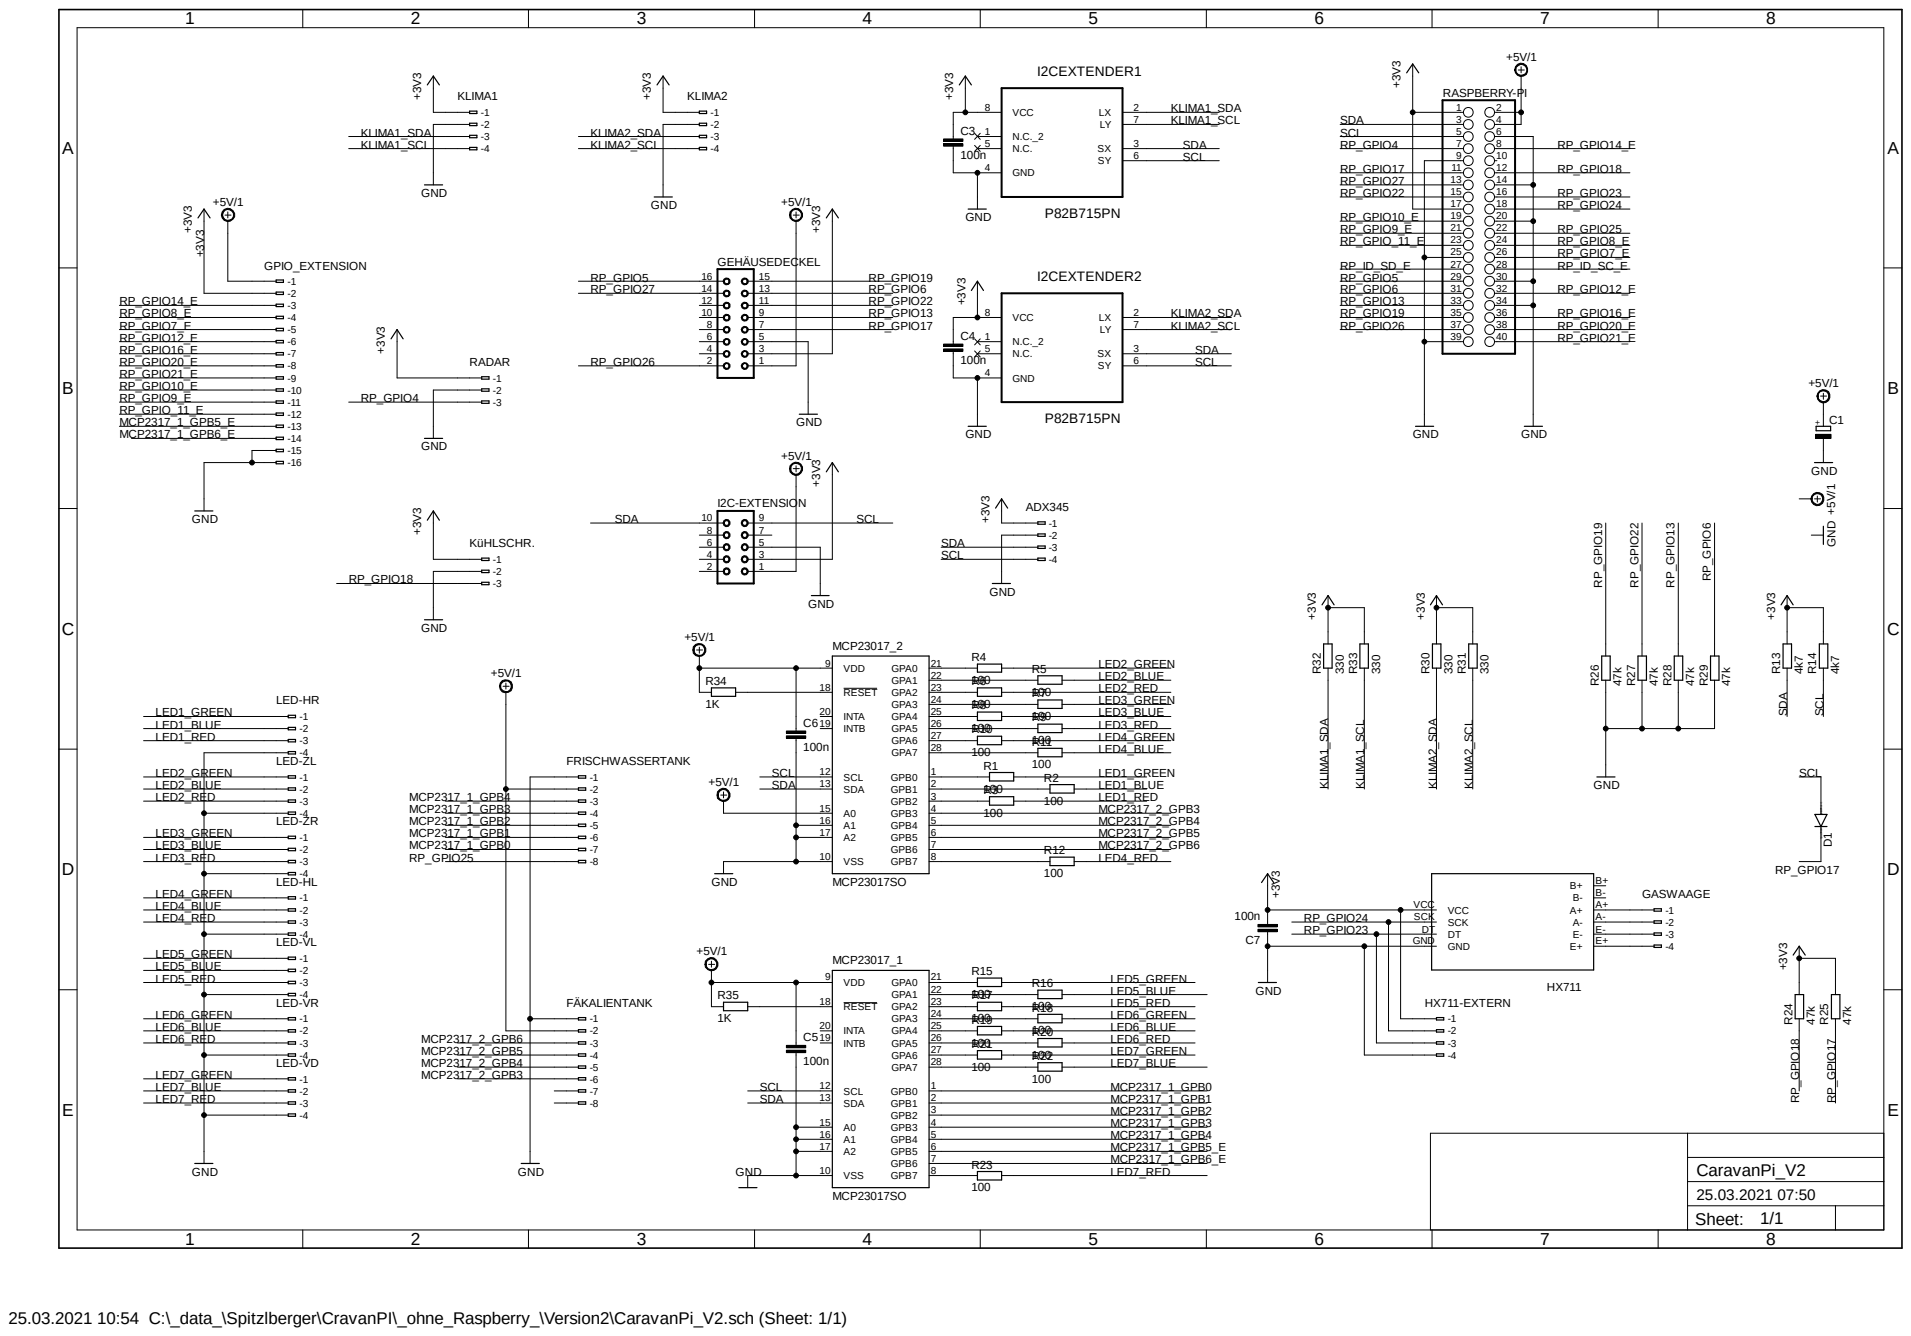
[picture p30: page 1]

25.03.2021 10:54 C:\_data_\Spitzlberger\CravanPI\_ohne_Raspberry_\Version2\CaravanPi_V2.sch (Sheet: 1/1)

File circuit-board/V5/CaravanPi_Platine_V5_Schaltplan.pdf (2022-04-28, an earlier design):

A

A

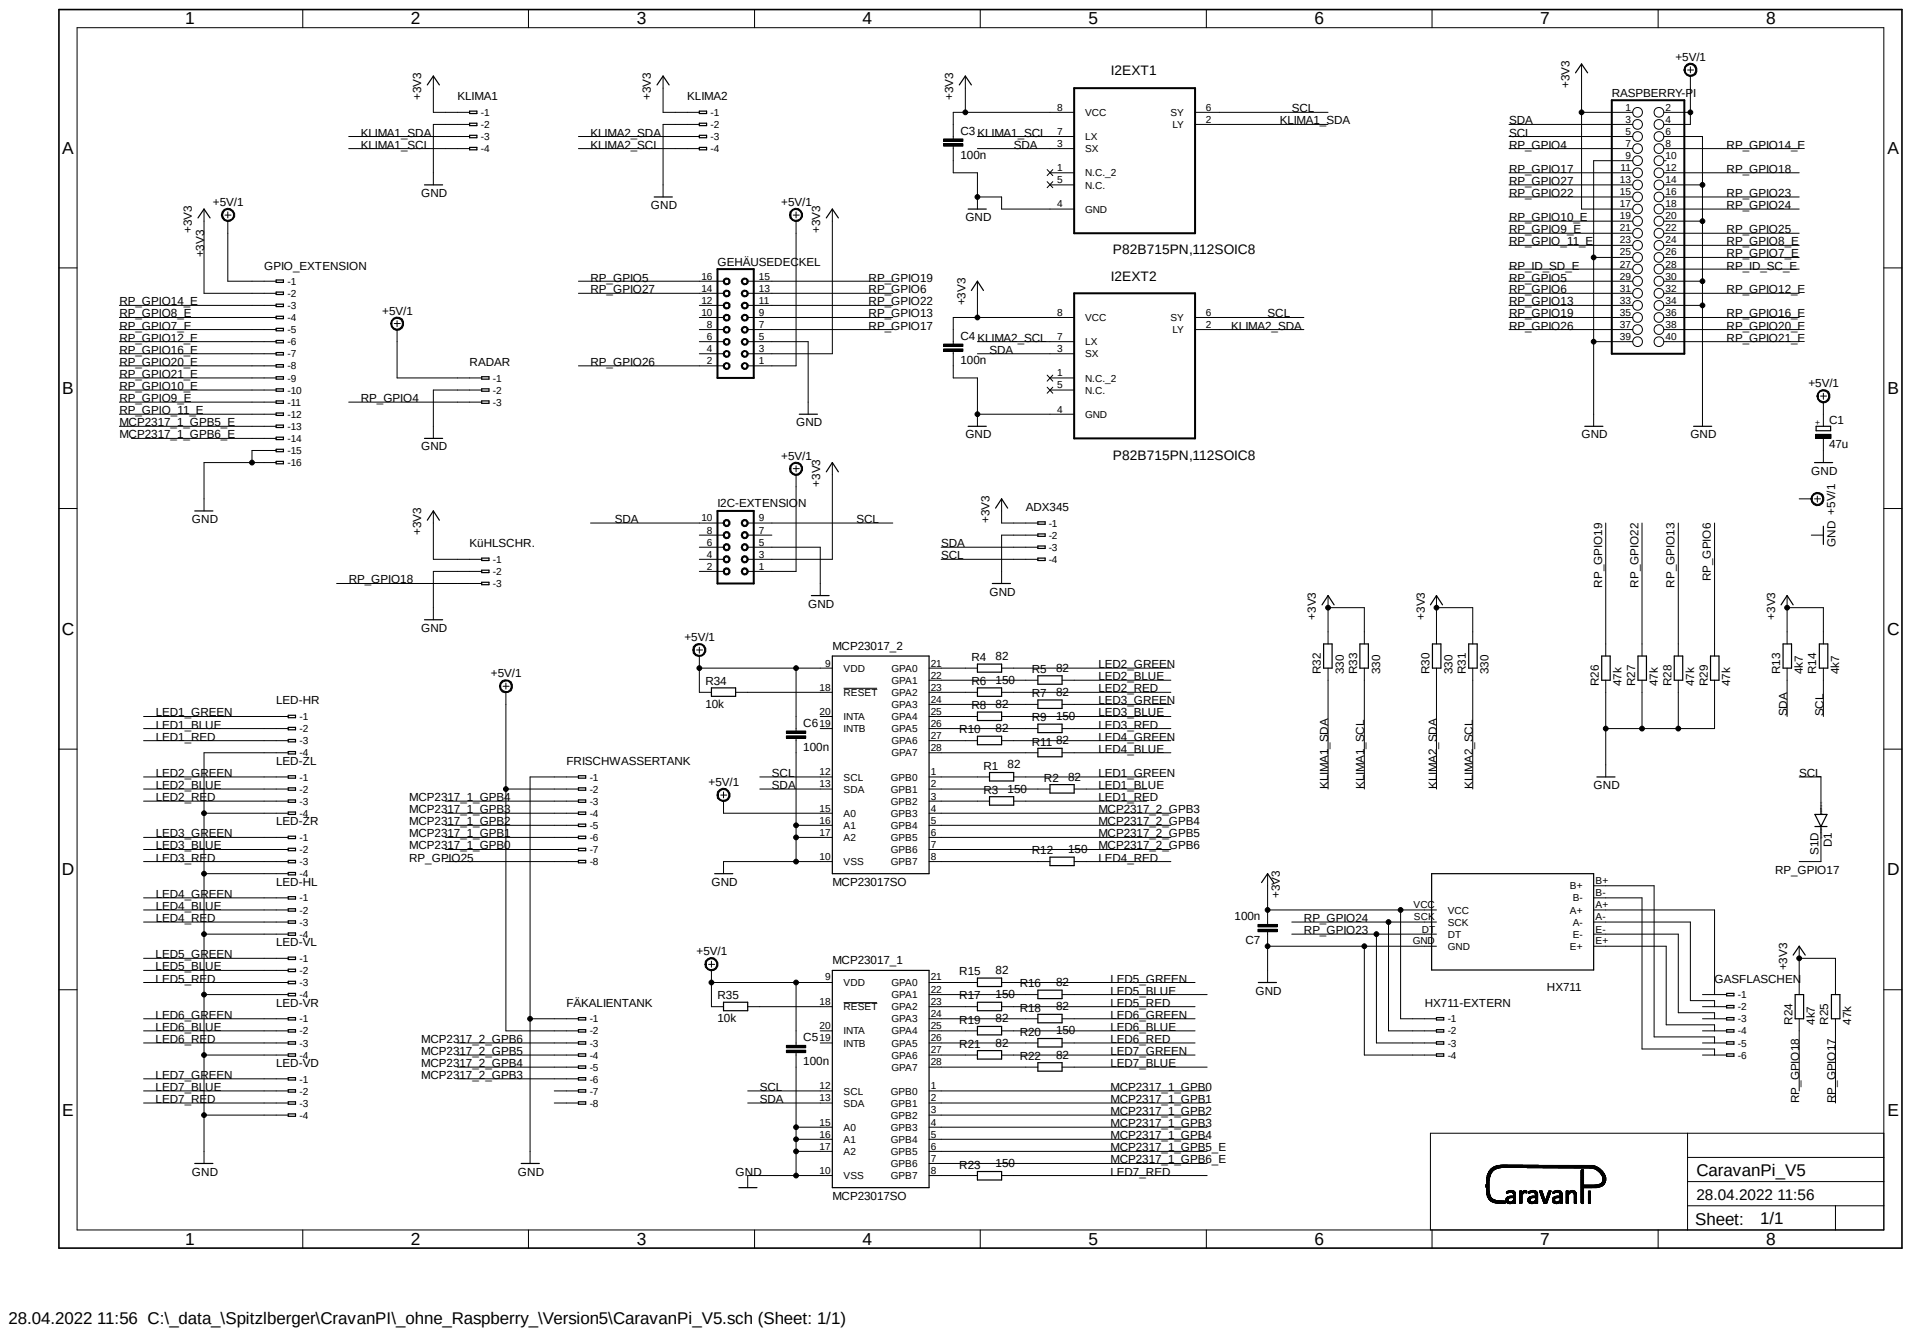
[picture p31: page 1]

KLIMA1_SCL 7 | | 2 KLIMA1_SDA

28.04.2022 11:56 C:\_data_\Spitzlberger\CravanPI\_ohne_Raspberry_\Version5\CaravanPi_V5.sch (Sheet: 1/1)

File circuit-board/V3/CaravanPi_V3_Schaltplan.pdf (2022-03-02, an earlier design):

A

A

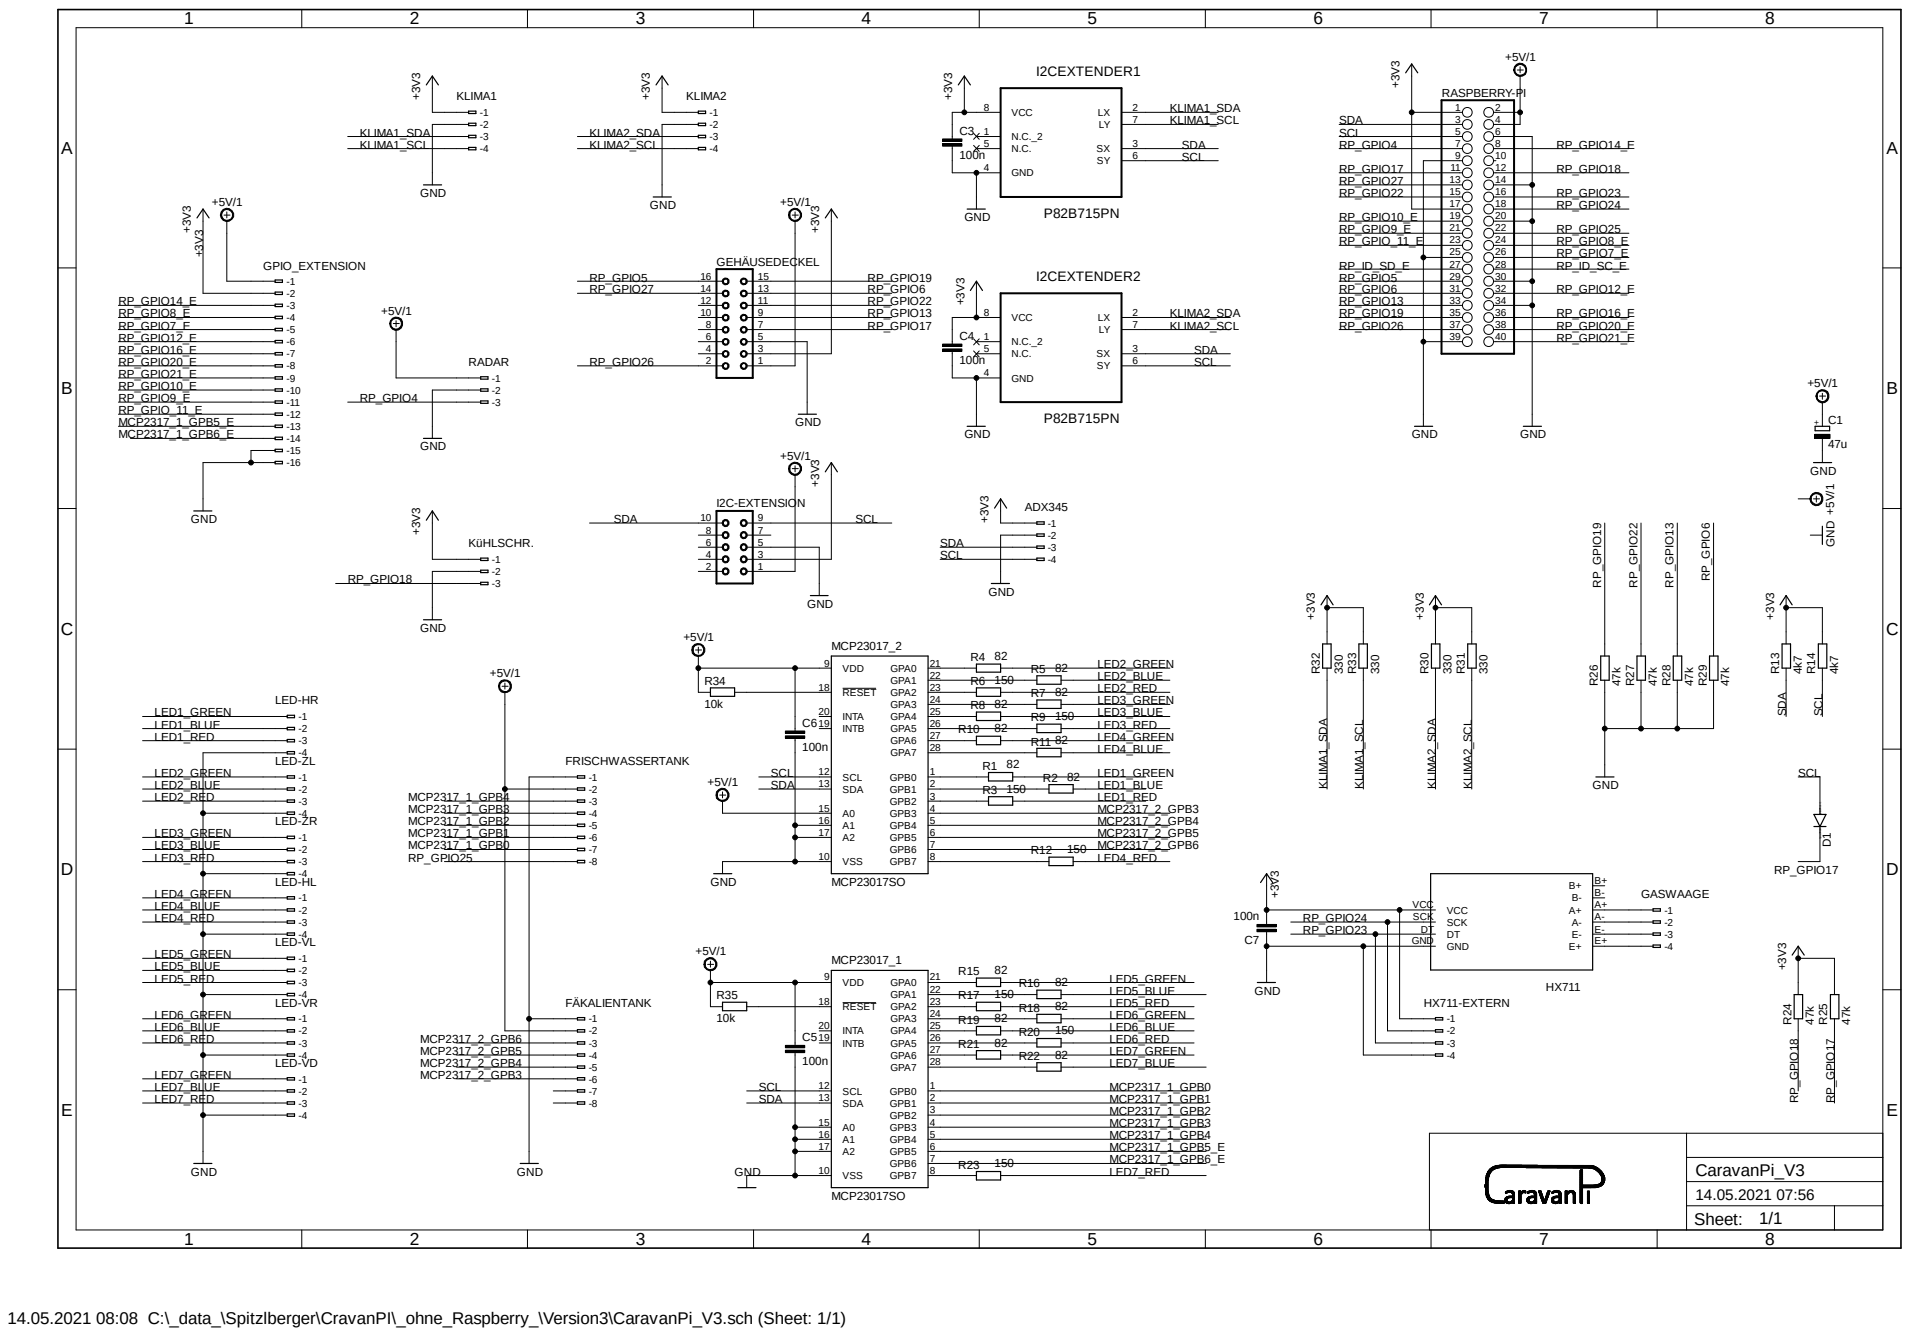
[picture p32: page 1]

14.05.2021 08:08 C:\_data_\Spitzlberger\CravanPI\_ohne_Raspberry_\Version3\CaravanPi_V3.sch (Sheet: 1/1)

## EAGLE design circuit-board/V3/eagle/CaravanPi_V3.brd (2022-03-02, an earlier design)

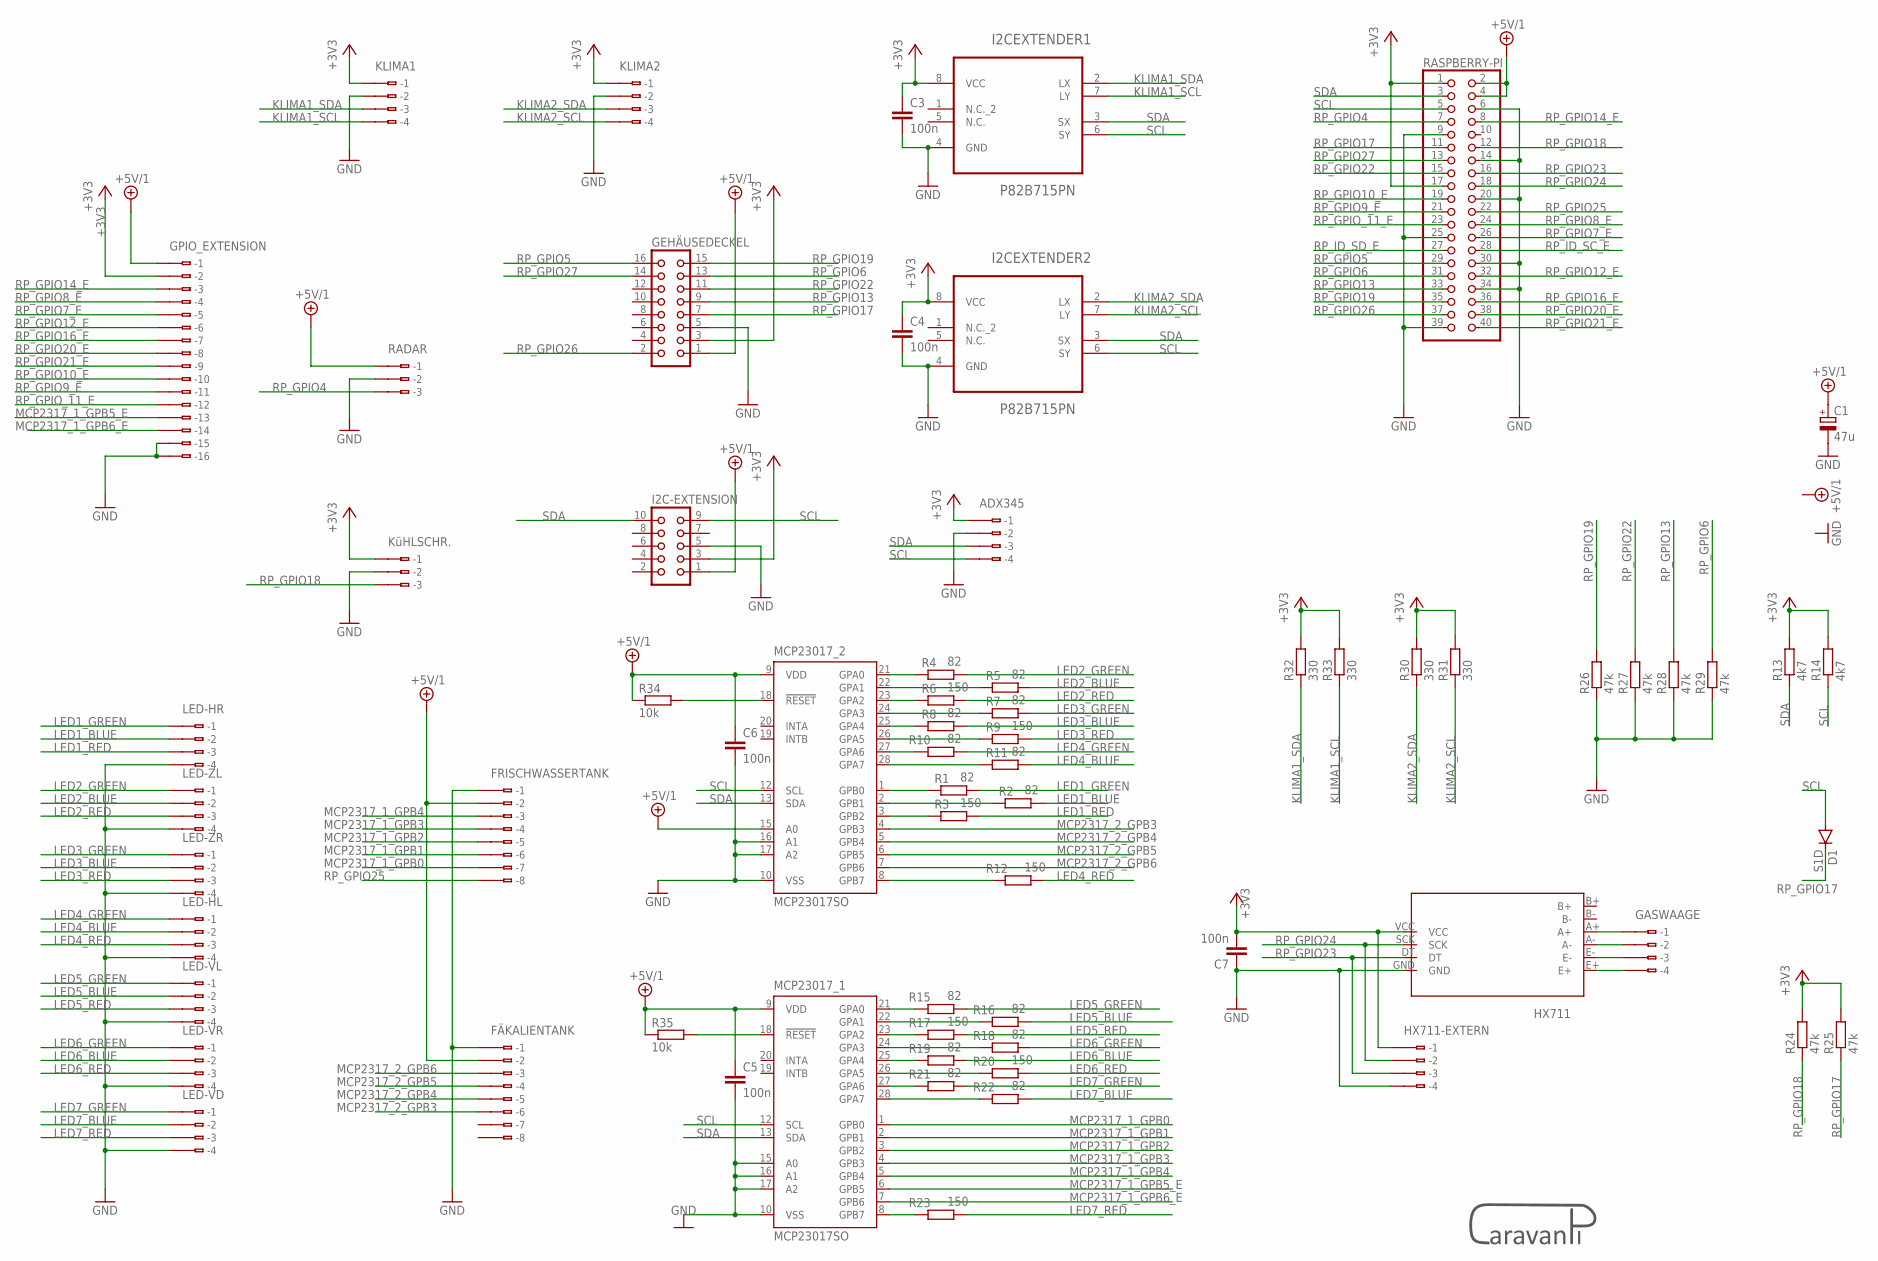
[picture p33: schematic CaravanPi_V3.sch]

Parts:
ADX345: 233-404
C1: 47u; SMC_C
C3, C4, C5, C6, C7: 100n; C1206
D1: S1D; DO214AC
FRISCHWASSERTANK: 233-408
FÄKALIENTANK: 233-408
GASWAAGE: 233-404
GEHÄUSEDECKEL: CON16
GPIO_EXTENSION: 233-516
HX711: HX711A; HX711
HX711-EXTERN: 233-404
I2C-EXTENSION: CON10
I2CEXTENDER1, I2CEXTENDER2: P82B715PN; DIP254P762X420-8
KLIMA1, KLIMA2: 233-404
KüHLSCHR.: 233-403
LED-HL: 233-504
LED-HR: 233-504
LED-VD: 233-504
LED-VL: 233-504
LED-VR: 233-504
LED-ZL: 233-504
LED-ZR: 233-504
MCP23017_1, MCP23017_2: MCP23017SO; SO28W
R1, R2, R4, R5, R7, R8, R10, R11, R15, R16, R18, R19, R21, R22: 82; M1206
R3, R6, R9, R12, R17, R20, R23: 150; M1206
R13, R14: 4k7; M1206
R24, R25, R26, R27, R28, R29: 47k; M1206
R30, R31, R32, R33: 330; M1206
R34, R35: 10k; M1206
RADAR: 233-403
RASPBERRY-PI: PINHD-2X20; 2X20
U$1: CARAVAN_PI_LOGO

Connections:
+3V3: ADX345.B1 (B-1), C3.1, C4.1, C7.2, GEHÄUSEDECKEL.3, GPIO_EXTENSION.B2 (B-2), HX711.VCC, HX711-EXTERN.B1 (B-1), I2C-EXTENSION.3, I2CEXTENDER1.8 (VCC), I2CEXTENDER2.8 (VCC), KLIMA1.B1 (B-1), KLIMA2.B1 (B-1), KüHLSCHR..B1 (B-1), R13.2, R14.2, R24.2, R25.2, R30.2, R31.2, R32.2, R33.2, RASPBERRY-PI.1, RASPBERRY-PI.17
+5V/1: C1.+, C5.1, C6.1, FRISCHWASSERTANK.B2 (B-2), FÄKALIENTANK.B2 (B-2), GEHÄUSEDECKEL.1, GPIO_EXTENSION.B1 (B-1), I2C-EXTENSION.1, MCP23017_1.9 (VDD), MCP23017_2.9 (VDD), MCP23017_2.15 (A0), R34.1, R35.1, RADAR.B1 (B-1), RASPBERRY-PI.2, RASPBERRY-PI.4
GND: ADX345.B2 (B-2), C1.-, C3.2, C4.2, C5.2, C6.2, C7.1, FRISCHWASSERTANK.B1 (B-1), FÄKALIENTANK.B1 (B-1), GEHÄUSEDECKEL.5, GPIO_EXTENSION.B15 (B-15), GPIO_EXTENSION.B16 (B-16), HX711.GND, HX711-EXTERN.B4 (B-4), I2C-EXTENSION.5, I2CEXTENDER1.4 (GND), I2CEXTENDER2.4 (GND), KLIMA1.B2 (B-2), KLIMA2.B2 (B-2), KüHLSCHR..B2 (B-2), LED-HL.B4 (B-4), LED-HR.B4 (B-4), LED-VD.B4 (B-4), LED-VL.B4 (B-4), LED-VR.B4 (B-4), LED-ZL.B4 (B-4), LED-ZR.B4 (B-4), MCP23017_1.10 (VSS), MCP23017_1.15 (A0), MCP23017_1.16 (A1), MCP23017_1.17 (A2), MCP23017_2.10 (VSS), MCP23017_2.16 (A1), MCP23017_2.17 (A2), R26.1, R27.1, R28.1, R29.1, RADAR.B2 (B-2), RASPBERRY-PI.6, RASPBERRY-PI.9, RASPBERRY-PI.14, RASPBERRY-PI.20, RASPBERRY-PI.25, RASPBERRY-PI.30, RASPBERRY-PI.34, RASPBERRY-PI.39
KLIMA1_SCL: I2CEXTENDER1.7 (LY), KLIMA1.B4 (B-4), R33.1
KLIMA1_SDA: I2CEXTENDER1.2 (LX), KLIMA1.B3 (B-3), R32.1
KLIMA2_SCL: I2CEXTENDER2.7 (LY), KLIMA2.B4 (B-4), R31.1
KLIMA2_SDA: I2CEXTENDER2.2 (LX), KLIMA2.B3 (B-3), R30.1
LED1_BLUE: LED-HR.B2 (B-2), R2.2
LED1_GREEN: LED-HR.B1 (B-1), R1.2
LED1_RED: LED-HR.B3 (B-3), R3.2
LED2_BLUE: LED-ZL.B2 (B-2), R5.2
LED2_GREEN: LED-ZL.B1 (B-1), R4.2
LED2_RED: LED-ZL.B3 (B-3), R6.2
LED3_BLUE: LED-ZR.B2 (B-2), R8.2
LED3_GREEN: LED-ZR.B1 (B-1), R7.2
LED3_RED: LED-ZR.B3 (B-3), R9.2
LED4_BLUE: LED-HL.B2 (B-2), R11.2
LED4_GREEN: LED-HL.B1 (B-1), R10.2
LED4_RED: LED-HL.B3 (B-3), R12.2
LED5_BLUE: LED-VL.B2 (B-2), R16.2
LED5_GREEN: LED-VL.B1 (B-1), R15.2
LED5_RED: LED-VL.B3 (B-3), R17.2
LED6_BLUE: LED-VR.B2 (B-2), R19.2
LED6_GREEN: LED-VR.B1 (B-1), R18.2
LED6_RED: LED-VR.B3 (B-3), R20.2
LED7_BLUE: LED-VD.B2 (B-2), R22.2
LED7_GREEN: LED-VD.B1 (B-1), R21.2
LED7_RED: LED-VD.B3 (B-3), R23.2
MCP2317_1_GPB0: FRISCHWASSERTANK.B7 (B-7), MCP23017_1.1 (GPB0)
MCP2317_1_GPB1: FRISCHWASSERTANK.B6 (B-6), MCP23017_1.2 (GPB1)
MCP2317_1_GPB2: FRISCHWASSERTANK.B5 (B-5), MCP23017_1.3 (GPB2)
MCP2317_1_GPB3: FRISCHWASSERTANK.B4 (B-4), MCP23017_1.4 (GPB3)
MCP2317_1_GPB4: FRISCHWASSERTANK.B3 (B-3), MCP23017_1.5 (GPB4)
MCP2317_1_GPB5_E: GPIO_EXTENSION.B13 (B-13), MCP23017_1.6 (GPB5)
MCP2317_1_GPB6_E: GPIO_EXTENSION.B14 (B-14), MCP23017_1.7 (GPB6)
MCP2317_2_GPB3: FÄKALIENTANK.B6 (B-6), MCP23017_2.4 (GPB3)
MCP2317_2_GPB4: FÄKALIENTANK.B5 (B-5), MCP23017_2.5 (GPB4)
MCP2317_2_GPB5: FÄKALIENTANK.B4 (B-4), MCP23017_2.6 (GPB5)
MCP2317_2_GPB6: FÄKALIENTANK.B3 (B-3), MCP23017_2.7 (GPB6)
unnamed: MCP23017_2.1 (GPB0), R1.1
unnamed: MCP23017_2.2 (GPB1), R2.1
unnamed: MCP23017_2.3 (GPB2), R3.1
unnamed: MCP23017_2.21 (GPA0), R4.1
unnamed: MCP23017_2.22 (GPA1), R5.1
unnamed: MCP23017_2.23 (GPA2), R6.1
unnamed: MCP23017_2.24 (GPA3), R7.1
unnamed: MCP23017_2.25 (GPA4), R8.1
unnamed: MCP23017_2.26 (GPA5), R9.1
unnamed: MCP23017_2.27 (GPA6), R10.1
unnamed: MCP23017_2.28 (GPA7), R11.1
unnamed: MCP23017_2.8 (GPB7), R12.1
unnamed: MCP23017_1.21 (GPA0), R15.1
unnamed: MCP23017_1.22 (GPA1), R16.1
unnamed: MCP23017_1.23 (GPA2), R17.1
unnamed: MCP23017_1.24 (GPA3), R18.1
unnamed: MCP23017_1.25 (GPA4), R19.1
unnamed: MCP23017_1.26 (GPA5), R20.1
unnamed: MCP23017_1.27 (GPA6), R21.1
unnamed: MCP23017_1.28 (GPA7), R22.1
unnamed: MCP23017_2.18 (!RESET), R34.2
unnamed: MCP23017_1.18 (!RESET), R35.2
unnamed: GASWAAGE.B4 (B-4), HX711.E+
unnamed: GASWAAGE.B3 (B-3), HX711.E-
unnamed: GASWAAGE.B2 (B-2), HX711.A-
unnamed: GASWAAGE.B1 (B-1), HX711.A+
unnamed: MCP23017_1.8 (GPB7), R23.1
RP_GPIO4: RADAR.B3 (B-3), RASPBERRY-PI.7
RP_GPIO5: GEHÄUSEDECKEL.16, RASPBERRY-PI.29
RP_GPIO6: GEHÄUSEDECKEL.13, R29.2, RASPBERRY-PI.31
RP_GPIO7_E: GPIO_EXTENSION.B5 (B-5), RASPBERRY-PI.26
RP_GPIO8_E: GPIO_EXTENSION.B4 (B-4), RASPBERRY-PI.24
RP_GPIO9_E: GPIO_EXTENSION.B11 (B-11), RASPBERRY-PI.21
RP_GPIO10_E: GPIO_EXTENSION.B10 (B-10), RASPBERRY-PI.19
RP_GPIO12_E: GPIO_EXTENSION.B6 (B-6), RASPBERRY-PI.32
RP_GPIO13: GEHÄUSEDECKEL.9, R28.2, RASPBERRY-PI.33
RP_GPIO14_E: GPIO_EXTENSION.B3 (B-3), RASPBERRY-PI.8
RP_GPIO16_E: GPIO_EXTENSION.B7 (B-7), RASPBERRY-PI.36
RP_GPIO17: D1.C, GEHÄUSEDECKEL.7, R25.1, RASPBERRY-PI.11
RP_GPIO18: KüHLSCHR..B3 (B-3), R24.1, RASPBERRY-PI.12
RP_GPIO19: GEHÄUSEDECKEL.15, R26.2, RASPBERRY-PI.35
RP_GPIO20_E: GPIO_EXTENSION.B8 (B-8), RASPBERRY-PI.38
RP_GPIO21_E: GPIO_EXTENSION.B9 (B-9), RASPBERRY-PI.40
RP_GPIO22: GEHÄUSEDECKEL.11, R27.2, RASPBERRY-PI.15
RP_GPIO23: HX711.DT, HX711-EXTERN.B3 (B-3), RASPBERRY-PI.16
RP_GPIO24: HX711.SCK, HX711-EXTERN.B2 (B-2), RASPBERRY-PI.18
RP_GPIO25: FRISCHWASSERTANK.B8 (B-8), RASPBERRY-PI.22
RP_GPIO26: GEHÄUSEDECKEL.2, RASPBERRY-PI.37
RP_GPIO27: GEHÄUSEDECKEL.14, RASPBERRY-PI.13
RP_GPIO_11_E: GPIO_EXTENSION.B12 (B-12), RASPBERRY-PI.23
RP_ID_SC_E: RASPBERRY-PI.28
RP_ID_SD_E: RASPBERRY-PI.27
SCL: ADX345.B4 (B-4), D1.A, I2C-EXTENSION.9, I2CEXTENDER1.6 (SY), I2CEXTENDER2.6 (SY), MCP23017_1.12 (SCL), MCP23017_2.12 (SCL), R14.1, RASPBERRY-PI.5
SDA: ADX345.B3 (B-3), I2C-EXTENSION.10, I2CEXTENDER1.3 (SX), I2CEXTENDER2.3 (SX), MCP23017_1.13 (SDA), MCP23017_2.13 (SDA), R13.1, RASPBERRY-PI.3

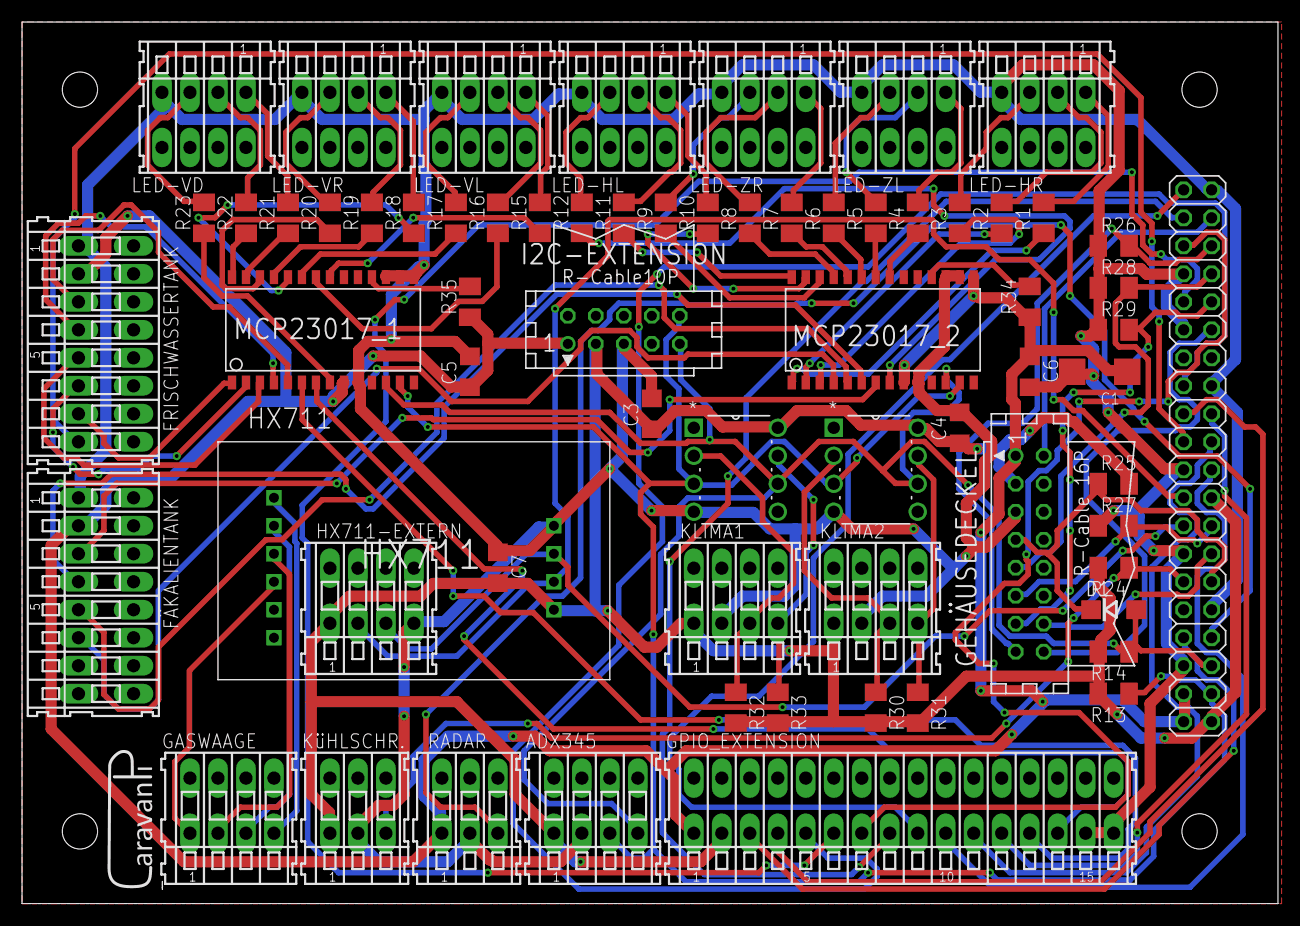
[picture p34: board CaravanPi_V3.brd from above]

Board: 2 copper layers, 114.0 x 80.0 mm, 68 parts (0 on the bottom side), 91 nets.

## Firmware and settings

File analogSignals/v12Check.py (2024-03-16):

#!/usr/bin/python
# coding=utf-8
# v12Check.py
#
# überprüft das Vorhandensein von 12V
# Dabei mehrere 12V Eingänge überwacht werden, bei geeignetem Parameter
#
# nutzt dazu einen Spannungsteiler, einen LevelConverter und einen ADC1115
# Wenn 12V nicht da ist oder ein zu niedriges Spannungslevel vorhanden ist, wird ein Alarmton ausgegeben
#
# ist ein ausreichendes Level wieder vorhanden, wird in den Defaults der Alarm wieder eingeschaltet, so dass ein 
# vorübergehend über die Config ausgeschalteter Alarm wieder aktiviert wird
#
#-------------------------------------------------------------------------------

import sys
import argparse
import time
from datetime import datetime 
import RPi.GPIO as GPIO
import board
import busio
import adafruit_ads1x15.ads1015 as ADS
from adafruit_ads1x15.analog_in import AnalogIn


# -----------------------------------------------
# CaravanPi File/MARIADB/MQTT library einbinden
# -----------------------------------------------
sys.path.append('/home/pi/CaravanPi/.lib')
from CaravanPiFilesClass import CaravanPiFiles
from CaravanPiFunctionsClass import CaravanPiFunctions

def berechne_spannungsteiler(R1, R2, Vin=None, Vout=None):
	# Innerhalb eines Spannungsteilers mit folgendem Aufbau
	#
	#     Vin ----- R1 ----- Vout ----- R2 ----- GND
	#
	# gilt folgende Formel
	# 
	#     Vout = Vin * ( R2 / (R1 + R2) )
	#
    if Vin is not None and Vout is None:
        # Berechne Vout aus Vin, R1 und R2
        Vout = Vin * (R2 / (R1 + R2))
        return Vout
    elif Vout is not None and Vin is None:
        # Berechne Vin aus Vout, R1 und R2
        Vin = Vout * ((R1 + R2) / R2)
        return Vin
    else:
        # Fehler, falls beide oder keine Spannungen angegeben sind
        print("Bitte geben Sie genau eine Spannung (entweder Vin oder Vout) an.")
        return None

def main():
	# ArgumentParser-Objekt erstellen
	parser = argparse.ArgumentParser(description='Überwachung der 12V Versorgung')
	parser.add_argument('-s', '--screen', action='store_true',
						help='Ausgabe auf dem Bildschirm')
	parser.add_argument('-c', '--check', action='store_true', 
						help='Führt den Funktionstest aus')
	parser.add_argument('-d', '--delay', type=str, default='30',
						help='Wartezeit zwischen zwei Messungen in Sekunden, default=30')
	parser.add_argument('-b', '--battery', type=str, choices=['car', 'bord'], default='bord',
						help='12V Anschluss wählen zwischen "bord" und "car", default = "bord"')

	# Argumente parsen
	args = parser.parse_args()
	delay = float(args.delay)
	delayAlarm = 1.5

	# Libraries anbinden
	cplib = CaravanPiFiles()
	cpfunc = CaravanPiFunctions()

	buzzer_pin = int(cplib.readCaravanPiConfigItem("caravanpiDefaults/BuzzerGPIOPin")) if cplib.readCaravanPiConfigItem("caravanpiDefaults/BuzzerGPIOPin") is not None else -1
	if buzzer_pin == -1:
		print("Buzzer GPIO Pin nicht richtig konfiguriert - Programmende")
		return False

	# ist die 12V Überwachung konfiguriert?
	if args.battery == "bord":
		v12CheckInstalled = cplib.typwandlung(cplib.readCaravanPiConfigItem("caravanpiDefaults/v12BatteryCheckInstalled"), "bool") if cplib.readCaravanPiConfigItem("caravanpiDefaults/v12BatteryCheckInstalled") is not None else False
		v12CheckADCPin = int(cplib.readCaravanPiConfigItem("caravanpiDefaults/v12BatteryCheckADCPin")) if cplib.readCaravanPiConfigItem("caravanpiDefaults/v12BatteryCheckADCPin") is not None else -1
		v12CheckAlarmActive = cplib.typwandlung(cplib.readCaravanPiConfigItem("caravanpiDefaults/v12BatteryCheckAlarmActive"), "bool") if cplib.readCaravanPiConfigItem("caravanpiDefaults/v12BatteryCheckAlarmActive") is not None else False
		v12CheckAlarmResume = cplib.typwandlung(cplib.readCaravanPiConfigItem("caravanpiDefaults/v12BatteryCheckAlarmResume"), "bool") if cplib.readCaravanPiConfigItem("caravanpiDefaults/v12BatteryCheckAlarmResume") is not None else False
		v12xmlItemAlarm = "v12BatteryCheckAlarmActive"
		v12R1 = int(cplib.readCaravanPiConfigItem("caravanpiDefaults/v12BatteryR1")) if cplib.readCaravanPiConfigItem("caravanpiDefaults/v12BatteryR1") is not None else 0
		v12R2 = int(cplib.readCaravanPiConfigItem("caravanpiDefaults/v12BatteryR2")) if cplib.readCaravanPiConfigItem("caravanpiDefaults/v12BatteryR2") is not None else 0

	elif args.battery == "car":
		v12CheckInstalled = cplib.typwandlung(cplib.readCaravanPiConfigItem("caravanpiDefaults/v12CarCheckInstalled"), "bool") if cplib.readCaravanPiConfigItem("caravanpiDefaults/v12CarCheckInstalled") is not None else False
		v12CheckADCPin = int(cplib.readCaravanPiConfigItem("caravanpiDefaults/v12CarCheckADCPin")) if cplib.readCaravanPiConfigItem("caravanpiDefaults/v12CarCheckADCPin") is not None else -1
		v12CheckAlarmActive = cplib.typwandlung(cplib.readCaravanPiConfigItem("caravanpiDefaults/v12CarCheckAlarmActive"), "bool") if cplib.readCaravanPiConfigItem("caravanpiDefaults/v12CarCheckAlarmActive") is not None else False
		v12CheckAlarmResume = cplib.typwandlung(cplib.readCaravanPiConfigItem("caravanpiDefaults/v12CarCheckAlarmResume"), "bool") if cplib.readCaravanPiConfigItem("caravanpiDefaults/v12CarCheckAlarmResume") is not None else False
		v12xmlItemAlarm = "v12CarCheckAlarmActive"
		v12R1 = int(cplib.readCaravanPiConfigItem("caravanpiDefaults/v12CarR1")) if cplib.readCaravanPiConfigItem("caravanpiDefaults/v12CarR1") is not None else 0
		v12R2 = int(cplib.readCaravanPiConfigItem("caravanpiDefaults/v12CarR2")) if cplib.readCaravanPiConfigItem("caravanpiDefaults/v12CarR2") is not None else 0
	else:
		print(f"falscher Battery Parameter - Skript beenden")
		return False

	# Skript beenden, falls Überwachung nicht installiert/konfiguriert
	if not v12CheckInstalled:
		print(f"keine 12V Überwachung für {args.battery} konfiguriert - Skript beenden")
		return False

	# Soll Werte an der Batterie
	v12Level1 = float(cplib.readCaravanPiConfigItem("voltageDefaults/level1")) if cplib.readCaravanPiConfigItem("voltageDefaults/level1") is not None else -1
	v12Level2 = float(cplib.readCaravanPiConfigItem("voltageDefaults/level2")) if cplib.readCaravanPiConfigItem("voltageDefaults/level2") is not None else -1
	v12Level3 = float(cplib.readCaravanPiConfigItem("voltageDefaults/level3")) if cplib.readCaravanPiConfigItem("voltageDefaults/level3") is not None else -1

	if v12Level1 == -1 or v12Level2 == -1 or v12Level3 == -1:
		print(f"Batterie Default Level nicht korrekt definiert ({v12Level1}, {v12Level2}, {v12Level3}) - Skript beenden")
		return False

	# Soll Werte nach Spannungsteiler
	v12Level1nSpT = berechne_spannungsteiler(v12R1, v12R2, Vin=v12Level1)
	v12Level2nSpT = berechne_spannungsteiler(v12R1, v12R2, Vin=v12Level2)
	v12Level3nSpT = berechne_spannungsteiler(v12R1, v12R2, Vin=v12Level3)

	print(f"ADC Pin: {v12CheckADCPin}, Alarm aktiv: {v12CheckAlarmActive}, Delay: {delay} Sekunden, Levels: {v12Level1}/{v12Level1nSpT}, {v12Level2}/{v12Level2nSpT}, {v12Level3}/{v12Level3nSpT}")

	# Verbindung zum AD Wandler herstellen
	connectOK = False
	try:
		# Create the I2C bus
		i2c = busio.I2C(board.SCL, board.SDA)

		# Create the ADC object using the I2C bus
		ads = ADS.ADS1015(i2c)

		connectOK = True
	except:
		print(f"AD Wandler nicht gefunden - Skript beenden")
		connectOK = False

	# nur Check?
	if args.check:
		# nur Check, daher Abschluss hier
		if connectOK:
			print("erfolgreich")
			return True
		else:
			print("Connect nicht möglich")
			return False

	# Connect fehlgeschlagen, dann beenden
	if not connectOK:
		return False
						  
	# GPIO für Buzzer initialisieren
	GPIO.setwarnings(False)
	GPIO.setmode(GPIO.BCM)
	
	# Create single-ended input on channel 0
	if v12CheckADCPin == 0: 
		channel = AnalogIn(ads, ADS.P0)
	elif v12CheckADCPin == 1: 
		channel = AnalogIn(ads, ADS.P1)
	elif v12CheckADCPin == 2: 
		channel = AnalogIn(ads, ADS.P2)
	elif v12CheckADCPin == 3: 
		channel = AnalogIn(ads, ADS.P3)
	else:
		print("AnalogIn Pin ist falsch, SOLL: 0 - 3, IST: {v12CheckADCPin}")
		return False
	
	errorcount = 0
	v12DropDetected = False
	zaehler = 0

	try: # Main program loop
		while True:  
			zaehler += 1  
			try:
				# Einlesen, ob Alarm ausgegeben werden soll
				v12CheckAlarmActive = cplib.typwandlung(cplib.readCaravanPiConfigItem(f"caravanpiDefaults/{v12xmlItemAlarm}"), "bool") if cplib.readCaravanPiConfigItem(f"caravanpiDefaults/{v12xmlItemAlarm}") is not None else False
				if not v12CheckAlarmActive:
					print("Alarm über Config ausgeschaltet")

				# Eine voll geladene Batterie gibt etwa 13.3 Volt aus, unter 12 Volt gilt eine Batterie als leer
				print(f"{datetime.now().strftime('%Y%m%d %H:%M:%S')}: ", "Analog: {:>5}, {:>5.2f}, ".format(channel.value, channel.voltage))

				if channel.voltage <= v12Level1nSpT:
					print(f"Batterie leer bei {berechne_spannungsteiler(v12R1, v12R2, Vout=channel.voltage):.2f}/{channel.voltage:.2f} Volt")
					# Batterie leer
					v12DropDetected = True
					# Alarm ausgeben, wenn nicht abgeschaltet
					if v12CheckAlarmActive:
						cpfunc.play_alarm_single(GPIO, buzzer_pin, 3)
				elif channel.voltage <= v12Level2nSpT:
					print(f"Batterie ok bei {berechne_spannungsteiler(v12R1, v12R2, Vout=channel.voltage):.2f}/{channel.voltage:.2f} Volt")
					# Batterie noch OK
					v12DropDetected = False
				elif channel.voltage > v12Level2nSpT and channel.voltage <= v12Level3nSpT:
					print(f"Batterie voll geladen bei {berechne_spannungsteiler(v12R1, v12R2, Vout=channel.voltage):.2f}/{channel.voltage:.2f} Volt")
					# Batterie voll
					v12DropDetected = False
				else:
					print(f"Batterie bei {berechne_spannungsteiler(v12R1, v12R2, Vout=channel.voltage):.2f}/{channel.voltage:.2f} Volt - seltsamer Zustand")
					# Batterie überladen oder defekt ??
					v12DropDetected = True
					# Alarm ausgeben, wenn nicht abgeschaltet
					if v12CheckAlarmActive:
						cpfunc.play_alarm_single(GPIO, buzzer_pin, 3)
					
				if channel.voltage > v12Level1 and channel.voltage <= v12Level3:
					if not v12CheckAlarmActive and v12CheckAlarmResume:
						# Alarm wieder einschalten
						print("Alarm in Config einschalten")
						cplib.writeCaravanPiConfigItem(f"caravanpiDefaults/{v12xmlItemAlarm}", 1)
						v12CheckAlarmActive = True
				
				if not v12DropDetected or (v12DropDetected and zaehler >= (delay/delayAlarm)):
					cplib.handle_sensor_values(
						args.screen,    		    # Anzeige am Bildschirm?
						"spannung",      			# sensor_name = Datenbankname 
						f"12v{args.battery}",     	# sensor_id = Filename und Spalte in der Datenbank
						["spannung"], 				# Liste Spaltennamen
						(berechne_spannungsteiler(v12R1, v12R2, Vout=channel.voltage),) # Tupel Sensorwerte
					)
					zaehler = 0


			except Exception as e:
				print(f"Fehler {e} ist aufgetreten")
				# alle anderen Fehler
				errorcount = errorcount + 1
				if errorcount > 30:
					print("zu viele Fehler")
					return False
				continue
				
			else:
				# kein Fehler aufgetreten
				errorcount = 0

			time.sleep(delayAlarm if v12DropDetected else delay)

	except KeyboardInterrupt:
		# Alarm ausgeben, dass nicht zufällig Dauerton verbleibt beim Abbrechen
		cpfunc.play_alarm_single(GPIO, buzzer_pin, 1)
		print('Script end!')
			

if __name__=="__main__":
	result = main()
	sys.exit(result)

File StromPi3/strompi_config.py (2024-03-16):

import serial
from time import sleep
import datetime
import os
import time
from time import sleep

wide_range_volt_min = 4.8
battery_volt_min = 0.5
mUSB_volt_min = 4.1

breakS = 0.1
breakL = 0.5

serial_port = serial.Serial()

serial_port.baudrate = 38400
serial_port.port = '/dev/serial0'
serial_port.timeout = 1
serial_port.bytesize = 8
serial_port.stopbits = 1
serial_port.parity = serial.PARITY_NONE

if serial_port.isOpen(): serial_port.close()
serial_port.open()

#######################################################################################################################

def enabled_disabled_converter(argument):
    switcher = {
        0: 'Disabled',
        1: 'Enabled',
    }
    return switcher.get(argument, 'nothing')

def weekday_converter(argument):
    switcher = {
        1: 'Monday',
        2: 'Tuesday',
        3: 'Wednesday',
        4: 'Thursday',
        5: 'Friday',
        6: 'Saturday',
        7: 'Sunday',
    }
    return switcher.get(argument, 'nothing')

def strompi_mode_converter(argument):
    switcher = {
        1: 'mUSB -> Wide',
        2: 'Wide -> mUSB',
        3: 'mUSB -> Battery',
        4: 'Wide -> Battery',
        5: "mUSB -> Wide -> Battery",
        6: "Wide -> mUSB -> Battery",
    }
    return switcher.get(argument, 'nothing')

def alarm_mode_converter(argument):
    switcher = {
        1: 'Time-Alarm',
        2: 'Date-Alarm',
        3: 'Weekday-Alarm',
        4: 'Wakeup Timer',
    }
    return switcher.get(argument, 'nothing')

def batterylevel_shutdown_converter(argument):
    switcher = {
        0: 'Disabled',
        1: '10%',
        2: '25%',
        3: '50%',
    }
    return switcher.get(argument, 'nothing')

def output_status_converter(argument):
    switcher = {
        0: 'Power-Off', #only for Debugging-Purposes
        1: 'mUSB',
        2: 'Wide',
        3: 'Battery',
    }
    return switcher.get(argument, 'nothing')


def batterylevel_converter(batterylevel,charging):

    if charging:
        switcher = {
            1: ' [10%] [charging]',
            2: ' [25%] [charging]',
            3: ' [50%] [charging]',
            4: ' [100%] [charging]',
        }
        return switcher.get(batterylevel, 'nothing')
    else:
        switcher = {
            1: ' [10%]',
            2: ' [25%]',
            3: ' [50%]',
            4: ' [100%]',
        }
        return switcher.get(batterylevel, 'nothing')

#######################################################################################################################
serial_port.write(str.encode('quit'))
sleep(breakS)
serial_port.write(str.encode('\x0D'))
sleep(breakL)

serial_port.write(str.encode('status-rpi'))
sleep(1)
serial_port.write(str.encode('\x0D'))
sp3_time = serial_port.readline(9999);
sp3_date = serial_port.readline(9999);
sp3_weekday = serial_port.readline(9999);
sp3_modus = serial_port.readline(9999);
sp3_alarm_enable = serial_port.readline(9999);
sp3_alarm_mode = serial_port.readline(9999);
sp3_alarm_hour = serial_port.readline(9999);
sp3_alarm_min = serial_port.readline(9999);
sp3_alarm_day = serial_port.readline(9999);
sp3_alarm_month = serial_port.readline(9999);
sp3_alarm_weekday = serial_port.readline(9999);
sp3_alarmPoweroff = serial_port.readline(9999);
sp3_alarm_hour_off = serial_port.readline(9999);
sp3_alarm_min_off = serial_port.readline(9999);
sp3_shutdown_enable = serial_port.readline(9999);
sp3_shutdown_time = serial_port.readline(9999);
sp3_warning_enable = serial_port.readline(9999);
sp3_serialLessMode = serial_port.readline(9999);
sp3_intervalAlarm = serial_port.readline(9999);
sp3_intervalAlarmOnTime = serial_port.readline(9999);
sp3_intervalAlarmOffTime = serial_port.readline(9999);
sp3_batLevel_shutdown = serial_port.readline(9999);
sp3_batLevel = serial_port.readline(9999);
sp3_charging = serial_port.readline(9999);
sp3_powerOnButton_enable = serial_port.readline(9999);
sp3_powerOnButton_time = serial_port.readline(9999);
sp3_powersave_enable = serial_port.readline(9999);
sp3_poweroffMode = serial_port.readline(9999);
sp3_poweroff_time_enable = serial_port.readline(9999);
sp3_poweroff_time = serial_port.readline(9999);
sp3_wakeupweekend_enable = serial_port.readline(9999);
sp3_ADC_Wide = float(serial_port.readline(9999))/1000;
sp3_ADC_BAT = float(serial_port.readline(9999))/1000;
sp3_ADC_USB = float(serial_port.readline(9999))/1000;
sp3_ADC_OUTPUT = float(serial_port.readline(9999))/1000;
sp3_output_status = serial_port.readline(9999);
sp3_powerfailure_counter = serial_port.readline(9999);
sp3_firmwareVersion = serial_port.readline(9999);
powerofftime_enabletest = (str(sp3_poweroff_time_enable, 'utf-8').rstrip('\n').zfill(2))
date = int(sp3_date)

strompi_year = int(sp3_date) // 10000
strompi_month = int(sp3_date) % 10000 // 100
strompi_day = int(sp3_date) % 100

strompi_hour = int(sp3_time) // 10000
strompi_min = int(sp3_time) % 10000 // 100
strompi_sec = int(sp3_time) % 100
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

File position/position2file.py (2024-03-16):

#!/usr/bin/python3
# coding=utf-8
# position2file.py
#
# nutzt die aus dem Beschleunigungssensor ADXL345 gelesenen Lagewerte
# um den Wohnwagen über LEDs auszurichten
#
# Aufruf-Parameter
# positionLive.py -f
# 	-h	display guide 
# 	-f	write values to file 
# 	-s	display values on screen 
#
#-------------------------------------------------------------------------------

import datetime
import statistics
import signal
import sys
from time import sleep
import argparse
from gpiozero import Button, LED

# imports for sensor ADXL345
import board
import busio
import adafruit_adxl34x

# imports for the calculation of position differences
import math

# import for GPIO Input tactile switches
# import RPi.GPIO as GPIO

# import for opening URL to change update Intervall on magic Mirror
import urllib.request
from urllib.error import URLError, HTTPError, ContentTooShortError

# -----------------------------------------------
# libraries from CaravanPi
# -----------------------------------------------
sys.path.append('/home/pi/CaravanPi/.lib')
from mcp23017 import mcp23017,pin
from CaravanPiLedClass import Led
from CaravanPiFilesClass import CaravanPiFiles

# -------------------------
# Library initialisieren
# -------------------------
cplib = CaravanPiFiles()
	


# -----------------------------------------------
# global variables
# -----------------------------------------------
# initiate 3-axis-sensor
i2c = busio.I2C(board.SCL, board.SDA)
accelerometer = adafruit_adxl34x.ADXL345(i2c)

# initiate GPIO port expander
mymcp1=mcp23017(1,0x20)
mymcp2=mcp23017(1,0x21)

# Correction of axis values
# x longitudinal direction
# y traverse direction
# z vertical direction
adjustX = 0
adjustY = 0
adjustZ = 0
# manual correction with tactile switch to mark the current position in transverse direction as horizontal
globY = 0
globAdjustY = 0
globAdjustSwitchY = 0
# what is still considered horizontal
toleranceX = 0
toleranceY = 0
# When should the approach color be selected?
approximationX = 0
approximationY = 0
# Distance of the 3-axis sensor to the right side (in driving direction) and to the front of the caravan 
# If the 3-axis sensor is mounted behind the axis (in driving direction), 
# the distance to the axis (distAxis) is positive. Otherwise this constant is negative.
# in mm
distRight = 0
distFront = 0
distAxis = 0
# dimensions Caravan (in mm)
lengthOverAll = 0
lengthBody = 0
width = 0

# live and non-live mode
# live mode: 
# - liveMode = 1
# - leds on
# - measurement every 1/10 second
# - switch 'now horizontal' is on
# non-live mode
# - liveMode = 0
# - leds off
# - Measurement every 60 seconds
# - switch 'now horizontal' out of order
liveMode = 0

# files
filePosition = "/home/pi/CaravanPi/values/position"

# LED threads
LED_HR = [None, None, None]
LED_HL = [None, None, None]
LED_ZR = [None, None, None]
LED_ZL = [None, None, None]
LED_VR = [None, None, None]
LED_VL = [None, None, None]
LED_Vo = [None, None, None]

# tactile switch to set the current position in transverse direction as horizontal
pinSwitchNowHorizontal = 6
# tactile switch to activate the 'live' mode
pinSwitchLive = 13
pinLEDLive = 5

LEDlive = None

# MagicMirror URL
MMMUrl = "http://127.0.0.1:8080/MMM-CaravanPiPosition/changeUpdateInterval"
MMMavailable = True
 
# -------------------------
# checke den MagicMirror, ob er Interrupts empfangen kann
# -------------------------

def check_url_and_execute(url):
	try:
		# Versuch, die URL zu öffnen und die Antwort zu lesen
		response = urllib.request.urlopen(url)
		# Prüfung des HTTP-Statuscode
		if response.status == 200:
			print(f"Die Website {url} ist erreichbar und der Befehl wurde erfolgreich ausgeführt.")
		else:
			print(f"Die Website {url} ist erreichbar, aber der Befehl führte zu einem HTTP-Fehler mit dem Statuscode: {response.status}")
		return response.status
	except HTTPError as e:
		# HTTP-Fehler (z.B. 404, 501, ...)
		print(f"Die Website {url} ist nicht erreichbar: HTTP-Fehler: {e.code} - {e.reason}")
		return -4
	except URLError as e:
		# URL-Fehler (z.B. kein Netzwerk, falsche Domain, ...)
		print(f"Die Website {url} ist nicht erreichbar: URL-Fehler {url}: {e.reason}")
		return -3
	except ContentTooShortError as e:
		# Der heruntergeladene Inhalt ist kürzer als erwartet
		print("Der heruntergeladene Inhalt ist kürzer als erwartet.")
		return -2
	except Exception as e:
		# alle anderen Fehler
		print(f"Ein unerwarteter Fehler ist aufgetreten: {url} - {e}")
		return -1

# -------------------------
# 3-axis-sensor 
# -------------------------

def write2file(toFile, toScreen, x, y, z, adjustX, adjustY, adjustZ, lastX, secondLastX, diffHL, diffHR, diffVL, diffVR, diffZL, diffZR, diffVo):
	global filePosition
	
	try:
		str_from_time_now = datetime.datetime.now().strftime("%Y%m%d%H%M%S")
		strX = '{:.6f}'.format(x)
		strY = '{:.6f}'.format(y)
		strZ = '{:.6f}'.format(z)
		strAdjustX = '{:.6f}'.format(adjustX)
		strAdjustY = '{:.6f}'.format(adjustY)
		strDiffHL = '{:.0f}'.format(diffHL)
		strDiffHR = '{:.0f}'.format(diffHR)
		strDiffVL = '{:.0f}'.format(diffVL)
		strDiffVR = '{:.0f}'.format(diffVR)
		strDiffZL = '{:.0f}'.format(diffZL)
		strDiffZR = '{:.0f}'.format(diffZR)
		strDiffVo = '{:.0f}'.format(diffVo)
		if (lastX == None):
			strLastX = "none"
		else:
			strLastX = '{:.6f}'.format(lastX)
		if (secondLastX == None):
			strSecondLastX = "none"
		else:
			strSecondLastX = '{:.6f}'.format(secondLastX)

		valueStr = "\n"+ str_from_time_now + " adjusted_tolerant " + strAdjustX + " " + strAdjustY + " original " + strX + " " + strY + " " + strZ + " last_secondlastX " + strLastX + " " + strSecondLastX + " differences " + strDiffHL + " " + strDiffHR + " " + strDiffZL + " " + strDiffZR + " " + strDiffVL + " " + strDiffVR + " " + strDiffVo

		if toFile == 1:
			file = open(filePosition, 'a')
			file.write(valueStr)
			file.close()
		
		if toScreen == 1:
			print(valueStr)
		
		return 0
	except:
		print("write2file: The file could not be written - unprocessed Error:", sys.exc_info()[0])
		raise
		return -1

# -------------------------
# adjust Threats for LEDs
# -------------------------

def setupVL(): # Platine LED5
	pinGreen=Led(mymcp1,"gpioa",0)
	pinBlue=Led(mymcp1,"gpioa",1)
	pinRed=Led(mymcp1,"gpioa",2)
	
	return ([pinRed, pinGreen, pinBlue])

def setupVR(): # Platine LED6
	pinGreen=Led(mymcp1,"gpioa",3)
	pinBlue=Led(mymcp1,"gpioa",4)
	pinRed=Led(mymcp1,"gpioa",5)
	
	return([pinRed, pinGreen, pinBlue])

def setupVo(): # Platine LED7
	pinGreen=Led(mymcp1,"gpioa",6)
	pinBlue=Led(mymcp1,"gpioa",7)
	pinRed=Led(mymcp1,"gpiob",7)
	
	return([pinRed, pinGreen, pinBlue])

def setupZL(): # Platine LED2
	pinGreen=Led(mymcp2,"gpioa",0)
	pinBlue=Led(mymcp2,"gpioa",1)
	pinRed=Led(mymcp2,"gpioa",2)
	
	return ([pinRed, pinGreen, pinBlue])

def setupZR(): # Platine LED3
	pinGreen=Led(mymcp2,"gpioa",3)
	pinBlue=Led(mymcp2,"gpioa",4)
	pinRed=Led(mymcp2,"gpioa",5)
	
	return ([pinRed, pinGreen, pinBlue])
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

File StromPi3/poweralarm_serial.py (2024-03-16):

#!/usr/bin/env python
# -*- coding: utf-8 -*-
import RPi.GPIO as GPIO
import time
import serial
import os
import smtplib
from email.mime.text import MIMEText
##############################################################################
# This is The config for the EMAIL notification
##############################################################################
SERVER =    'SMTP.Server.Com'
PORT =      587
EMAIL =    'Example@Example.com'
PASSWORT =  'Password'
EMPFAENGER =    ['EmpfÃ¤nger@Example.com' ,]
SUBJECT_Powerfail =   'Raspberry Pi Powerfail!'  #Powerfail Email Betreff
SUBJECT_Powerback =   'Raspberry Pi Powerback!'  #Powerback Email Betreff
SUBJECT_Restart =     'Raspberry Pi Restart!'    #Restart Email Betreff
##############################################################################
# Here you can choose whether you want to receive an email when the Raspberry Pi restarts - 1 to activate - 0 to deactivate
Restart_Mail = 0
##############################################################################
t=0 #Temporary time-variable
##############################################################################

def Detect_Powerfail():
    while 1:
     x=ser.readline()
     y = x.decode(encoding='UTF-8',errors='strict')
     if y==('xxxShutdownRaspberryPixxx\n') or y==('xxx--StromPiPowerfail--xxx\n'):
      print ("PowerFail - Email Sent")
      Sendmail_Powerfail()

def Sendmail_Powerback():
    BODY =      """
    <html>
     <head></head>
      <body>
    <style type="text/css">
    .tg  {border-collapse:collapse;border-spacing:0;}
    .tg td{font-family:Arial, sans-serif;font-size:14px;padding:10px 5px;border-style:solid;border-width:1px;overflow:hidden;word-break:normal;}
    .tg th{font-family:Arial, sans-serif;font-size:14px;font-weight:normal;padding:10px 5px;border-style:solid;border-width:1px;overflow:hidden;word-break:normal;}
    .tg .tg-0ord{text-align:right}
    .tg .tg-qnmb{font-weight:bold;font-size:16px;text-align:center}
    </style>
    <table class="tg">
     <tr>
      <th class="tg-qnmb" colspan="2">StromPi hat Spannung wiedererkannt!</th>
     </tr>
    </table>
     </body>
    </html>
    """

    session = smtplib.SMTP(SERVER, PORT)
    session.set_debuglevel(1)
    session.ehlo()
    session.starttls()
    session.ehlo
    session.login(EMAIL, PASSWORT)
    msg = MIMEText(BODY, 'html')
    msg['Subject'] = SUBJECT_Powerback
    msg['From'] = EMAIL
    msg['To'] = ", ".join(EMPFAENGER)
    session.sendmail(EMAIL, EMPFAENGER, msg.as_string())
    Detect_Powerfail()

def Sendmail_Restart():
    BODY =      """
    <html>
     <head></head>
      <body>
    <style type="text/css">
    .tg  {border-collapse:collapse;border-spacing:0;}
    .tg td{font-family:Arial, sans-serif;font-size:14px;padding:10px 5px;border-style:solid;border-width:1px;overflow:hidden;word-break:normal;}
    .tg th{font-family:Arial, sans-serif;font-size:14px;font-weight:normal;padding:10px 5px;border-style:solid;border-width:1px;overflow:hidden;word-break:normal;}
    .tg .tg-0ord{text-align:right}
    .tg .tg-qnmb{font-weight:bold;font-size:16px;text-align:center}
    </style>
    <table class="tg">
     <tr>
      <th class="tg-qnmb" colspan="2">Ihr Raspberry Pi wurde neugestartet.</th>
     </tr>
    </table>
     </body>
    </html>
    """

    session = smtplib.SMTP(SERVER, PORT)
    session.set_debuglevel(1)
    session.ehlo()
    session.starttls()
    session.ehlo
    session.login(EMAIL, PASSWORT)
    msg = MIMEText(BODY, 'html')
    msg['Subject'] = SUBJECT_Restart
    msg['From'] = EMAIL
    msg['To'] = ", ".join(EMPFAENGER)
    session.sendmail(EMAIL, EMPFAENGER, msg.as_string())
    Detect_Powerfail()
 
def Sendmail_Powerfail():
    BODY =      """
    <html>
     <head></head>
      <body>
    <style type="text/css">
    .tg  {border-collapse:collapse;border-spacing:0;}
    .tg td{font-family:Arial, sans-serif;font-size:14px;padding:10px 5px;border-style:solid;border-width:1px;overflow:hidden;word-break:normal;}
    .tg th{font-family:Arial, sans-serif;font-size:14px;font-weight:normal;padding:10px 5px;border-style:solid;border-width:1px;overflow:hidden;word-break:normal;}
    .tg .tg-0ord{text-align:right}
    .tg .tg-qnmb{font-weight:bold;font-size:16px;text-align:center}
    </style>
    <table class="tg">
     <tr>
      <th class="tg-qnmb" colspan="2">StromPi hat einen STROMAUSFALL erkannt!!!!</th>
     </tr>
    </table>
     </body>
    </html>
    """

    session = smtplib.SMTP(SERVER, PORT)
    session.set_debuglevel(1)
    session.ehlo()
    session.starttls()
    session.ehlo
    session.login(EMAIL, PASSWORT)
    msg = MIMEText(BODY, 'html')
    msg['Subject'] = SUBJECT_Powerfail
    msg['From'] = EMAIL
    msg['To'] = ", ".join(EMPFAENGER)
    session.sendmail(EMAIL, EMPFAENGER, msg.as_string())
    Detect_Powerback()

def Detect_Powerback():
    while 1:
     x=ser.readline()
     y=x.decode(encoding='UTF-8',errors='strict')
     if y==('xxx--StromPiPowerBack--xxx\n'):
      print ("PowerBack - Email Sent")
      Sendmail_Powerback()

ser = serial.Serial(
 port='/dev/serial0',
 baudrate = 38400,
 parity=serial.PARITY_NONE,
 stopbits=serial.STOPBITS_ONE,
 bytesize=serial.EIGHTBITS,
 timeout=1
)
counter=0

time.sleep(5) 
if Restart_Mail == 1:
  Sendmail_Restart()




	  
	  
	  
Detect_Powerfail()

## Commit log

2019-08-30 Add features and update
    add pishutdown
    add backup crontabs
    update klima, LED, Gewicht
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2019-11-03 improvemnts to position2file, tactileSwitch, send SIGUSR1 in case of setupDefaults via switch
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2020-08-29 Changed LED Pin to BCM27
    Changed from BCM21 to BCM27
    all Pins for the operate panel to the GPIO odd side
2020-08-29 Changed Pins
    tactile switch calibration gasscale pin changed from BCM24 to BCM22
    tactile switch calibration position sensor pin changed from BCM23 to BCM 19
    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
2020-08-29 Changed pins
    tactile switch to set the current position in transverse direction as horizontal pin changed from BCM12 to BCM6
    LED live Mode pin changed from BCM16 to BCM5
    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
2020-08-29 changed pins
    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
2020-08-29 changed pir pin
    pir data pin changed from BCM25 to BCM4
    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
2020-09-06 PIR Sensor am Testgerät auslesen
    PIR Sensor mit den Testgerät (Raspberry Pi mit Testaufsatz) testen und optimalen Einbauort finden
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2020-10-23 Lösung für issue One-Digit-Temperature
    Umstellung der Formatierung des Temperaturwerts in Zeile 44 sowie Anpassung der Aufbereitung beim Schrieben in die Datei (Einfügen eines Spaces)
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2021-05-13 Upload all files to order a circuit board
    [copper_bottom.gbr, copper_top.gbr, gerber_job.gbrjob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]
2021-05-13 circuit to circuit-board
    [CaravanPi_V2.brd, CaravanPi_V2.sch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]
2021-05-13 neue Version für Fäkalientank
    periodische Abfrage der Reed Kontakte alle 10 Minuten
2021-05-14 circuit board Version 3 gerber files
    The circuit board version 2 is faulty. The connection for the radar sensor must be supplied with 5V instead of 3.3V. The circuit board version 3 fixes this error
    [copper_bottom.gbr, copper_top.gbr, gerber_job.gbrjob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]
2021-05-14 Delete profile.gbr
    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
    [profile.gbr]
2021-05-14 Delete silkscreen_bottom.gbr
    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
    [silkscreen_bottom.gbr]
2021-05-14 Delete silkscreen_top.gbr
    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
    [silkscreen_top.gbr]
2021-05-14 Delete solderpaste_bottom.gbr
    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
    [solderpaste_bottom.gbr]
2021-05-14 Delete solderpaste_top.gbr
    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
    [solderpaste_top.gbr]
2021-05-14 circuit board version 3
    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
    [profile.gbr, silkscreen_bottom.gbr, silkscreen_top.gbr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]
2021-05-14 circuit board version 2 is faulty
    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
    [CaravanPi_V2.brd]
2021-05-14 circuit board version 2 is faulty --> version 3
    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
    [CaravanPi_V3_Bauteile.xlsx]
2021-05-14 circuit board version 2 is faulty
    [CaravanPi_V2_Bauteile.xlsx]
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2021-05-15 gerber only as zip file necessary
    [copper_bottom.gbr]
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2021-05-21 circuit board mearurements
    [CaravanPi_V3.brd]
2021-06-01 Halterungen für die Reed Kontakte am Fäkalientank
    [ReedKontakteHalterung-ReedKontaktAufnahme.stl, ReedKontakteHalterung-SockelSenkrechtKlebeplatte.stl, ReedKontakteHalterung-SockelWaagrechtKlebeplatte.stl]
2021-06-01 FreeCAD File für Reed Kontakte Halterung
    Diese Konstruktion ist voll parametrisch und kann über ein FreeCAD Spreadsheet individuell angepasst werden.
    [ReedKontakteHalterung.FCStd]
2021-06-13 circuit board order process at JLCPCB
    [CaravanPi_V3_20210609-BOM.xls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]
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2021-06-25 creation of subdirectories at circuit board
    Version 3 - first finale Version for external circuit board production with P82B175B as THT (through hole technology) device
    Version 4 - P82B175B as SMD (surface-mounted device)
2021-06-28 JLCPCB Files added
    Problem: cann't find a SMD version of the P82B715P
    [CaravanPI-Platine-V4-BOM-20210628.xlsx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]
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2021-12-29 resistor id changed because original one was out of stock
    [CaravanPi_V3_20211229-BOM-R13-14-ersetzt.xlsx]
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2022-04-28 V5 der CaravanPi Platine
    - reine SMD Platine, keine bedrahteten Bauteile mehr
    - Fehlerkorrektur beim Widerstand R24 - 1-wire-Bus, nun 4k7 anstatt fälschlicherweise 47k
    - Gaswaagen-Klemme nun 6 Polig, um A und B Kanal des HX711 auf Klemmen zu führen
    [CaravanPi_Platine_V5_Bauteile.xlsx]
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2023-01-08 Korrektur der falschen Kalibrierung der Gaswaagen
    Einführung mehrerer Gaswaagen auch in der Kalibrierung
    Korrektur der falschen Kalibrierungsweise in der HTML Oberfläche
    Aufnahme der GPIO Parameter für die Steuerung der Gaswaagen Abfrage und die Ansteuerung der HX711 über diese Parameter
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2023-02-23 V5 Gerber-File, BOM-File, CPL-File
    [CaravanPi_V5_BOM-File_2023-02-19.xlsx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]
2023-04-11 BOM file updated,part placement image
    BOM file updated due to part outage at JLCPPCB
    additional image with the correct parts placement
    [CaravanPi_V5_BOM-File_2023-04-11.xlsx]
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2023-12-30 Konfig Datei auf xml umgestellt
    die bisherigen Konfigurationsdateien im .txt Format wurden auf eine einzige xml Datei umgestellt. Das Skript ist abwärtskompatibel und wandelt beim ersten Ausführen die bisherigen Konfigurationsdatei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
2023-12-31 Schreiben in MariaDB, senden an MQTT Broker, Systemzustände
    Die CaravanPiFilesClass wurde ergänzt um Funktionen zum Schreiben in eine mariaDB und zum Senden an einen MQTT Broker. Die zugehören Anmeldedaten werden aus der Config-xml gelesen. Im Verzeichnis raspberryPi wurde ein Skript erstellt, dass Systemzustände ausliest, damit diese in eine Datei/Datenbank/MQTT Broker geschrieben/gesendet werden können
    [CaravanPiFilesClass.py, climate2file.py]
2024-01-02 zentrale Sensorwert Verarbeitung (File,DB,MQTT)
    in der CaravnPiFiles Class wurde eine zentrale Funktion geschaffen, die zukünftig alle Schreib Vorgänge für Sensorwerte übernimmt. Die Funktion gibt am Bildschirm aus, schreibt die Werte in ein File,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
2024-01-02 Fehlerzustände
    Fehlerzustände werden nun mit ERROR oder WARNING deutlich in den Bildschirmausgaben bzw. Logdaten Einträgen markiert
    [CaravanPiFilesClass.py, climate2file.py]
2024-01-02 behandlung von sensiblen Daten
    um Passworte etc, die z.B. in der xml Datei in meiner Entwiclungsumgebung vorhanden sind, nicht auf github hochzuladen, habe ich git hooks angelegt
2024-01-03 Flask Website ersetzt alle anderen
    Mit Flask werden alle bisherigen Webseiten rund um den CaravanPi zusammengeführt. Mit diesen Arbeiten ist begonnen. Ebenfalls begonnen ist die Arbeit am Skript gasScale2File.py
2024-01-06 diverse Änderungen, Flask Websites
    weitere Härtung einiger pythonskripte, weiterer Aufbau der Flask Websites als Ersatz für die bisherigen Websites
2024-02-18 weitere Seiten für Config, Calibration, usw. in Flask
    Die Defaults Datei wurde an einigen Stellen erweitert, damit auch die librarys. In Flask wurde die Checks erweitert um crontab und Netzwerk. Die Konfiguration von Defaults, Gaswaagen Lagensensor, Tanks Batterie wurde ermöglicht. Flask kann nun auch die Config anzeigen, den Raspberry rebooten und stoppen. In Flask wurde die Kalibrierung der Gaswaage und des lagesensors ermöglicht
    [CaravanPiFilesClass.py, CaravanPiFunctionsClass.py, bme280.py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]
2024-03-02 flask website weiterentwickelt, configs weiterentwickelt, 230V Check, Gas Check, BatteryMgmt Liontron
    Die Flask Webseite wurde um Test Routinen, weiter Configs und Checks erweitert. Die Gaswaagen wurden getestet, aber sind noch nicht fertig. Die mariaDB wird nun bereinigt. Ein AD Wandler wurde integriert. Damit werden 230V und 12V überwacht, sowie ein Gassensor MQ-2. Für den Buzzer wurden Melodien eingefügt. Die Installation wurde bereinigt, obsoletes entsprechend markiert und verschoben.
    [CaravanPiFilesClass.py, CaravanPiFunctionsClass.py, analogRead.py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]
2024-03-03 git hooks, gassensor-, 230v-, 12v-Checks fertig, flask button menues
    git: Hooks ergänzt, so dass crontabs jeweisl mitgesichert werden; Gassensor, 230V und 12V Check Routinen abgeschlossen; Flask sites: menüs alle auf Buttons umgestellt; Flask sites: Aktoren eingebaut
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2024-03-15 Platine V6, StromPi Installtion im Skript, Tank-Routinen aktualisiert, gpiozero in position und Taster eingebaut
    [CaravanPi_V6_front_bom.csv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]
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2024-03-19 Platine V6 BOM und CPL vervollständigt und auf JLCPCB erfolgreich getestet
    [CaravanPi_V6_BOM-File_2024-03-19.xlsx, CaravanPi_V6_front_bom.csv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]
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
